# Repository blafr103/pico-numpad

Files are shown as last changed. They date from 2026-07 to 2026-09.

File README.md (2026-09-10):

# pico-numpad

Custom-built 17-key USB HID numpad powered by a Raspberry Pi Pico W,
featuring a hand-wired switch matrix, 16×2 LCD interface,
host-integrated PC monitoring, weather display, and onboard calculator.

The enclosure, electronics, and firmware were designed specifically for
this project using CircuitPython with event-driven matrix scanning via
`keypad.KeyMatrix`.

This README documents the hand-wired prototype. A custom two-layer PCB
successor built around a bare RP2040 is documented in
[`hardware/`](hardware/).

## Features

- USB HID numeric keypad
- Event-driven matrix scanning (`keypad.KeyMatrix`)
- 16x2 LCD with switchable views:
  - Clock + weather (current conditions and local time for one of
    four preset Canadian locations; date + time synced from the host)
  - PC stats, 4 cycling pages: overview (CPU/GPU utilization,
    temperature, package power), memory (RAM utilization, DIMM
    temperatures, VRAM), clocks (P/E-core max, GPU, TjMax
    distance), and voltages
  - Calculator (+ - * / with standard precedence; expression on
    row 0, result on Enter; keys are captured while active and
    send nothing to the PC)
  - Lifetime keypress statistics
- NumLock doubles as a momentary Fn key:
  - Fn+0: Clock view; pressed again while on it, cycles the
    weather location
  - Fn+1: PC stats view; pressed again while on it, cycles the
    stat pages
  - Fn+2: Calculator view; pressed again while on it, clears
  - Fn+3: Statistics view
  - Fn+'+': Increase keypad LED brightness
  - Fn+'-': Decrease keypad LED brightness
- Persistent settings (lifetime key counter and LED brightness) are stored in the
CircuitPython filesystem (`/count.txt` on internal flash).
- Automatic LCD backlight/LED timeout after 300 seconds of inactivity
- Optional Python companion application providing local time,
weather (Environment Canada API), and PC hardware monitoring.

<p align="center">
  <table align="center">
    <tr>
      <td align="center" width="450" valign="top">
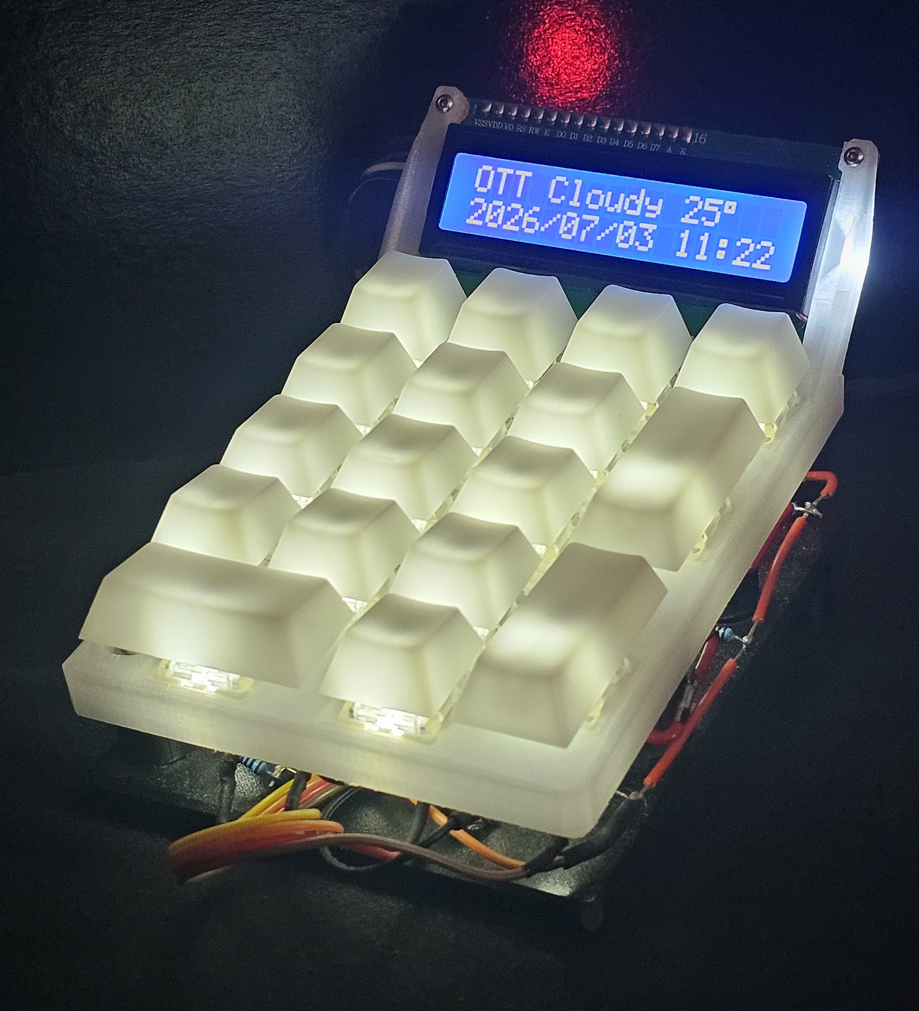
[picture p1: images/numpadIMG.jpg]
        <br>
        <b>Finished Device</b>
      </td>
      <td align="center" width="470" valign="top">
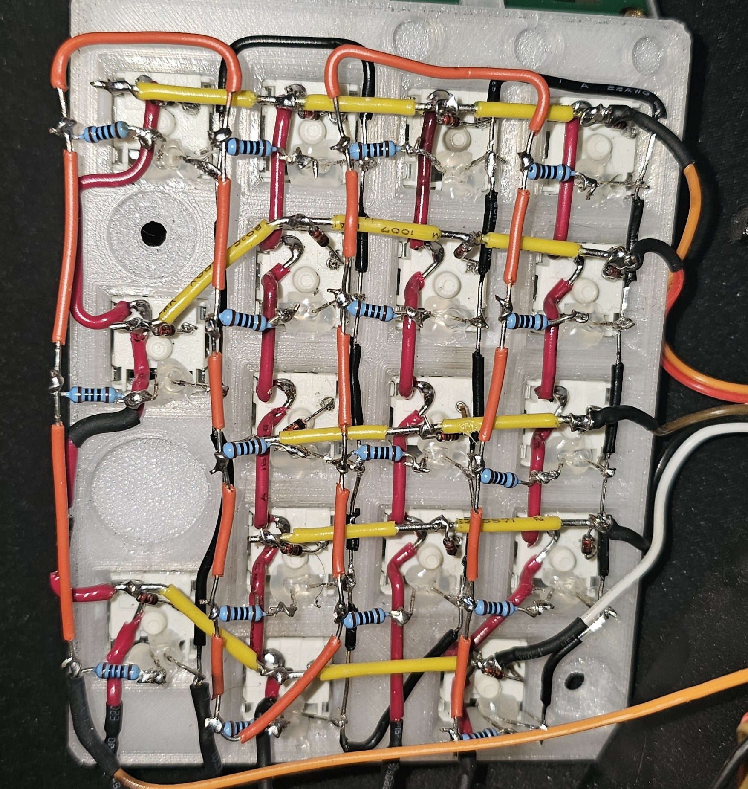
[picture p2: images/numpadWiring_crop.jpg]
        <br>
        <b>Hand-Wired Matrix</b>
      </td>
    </tr>
  </table>
</p>

## Physical Construction

This prototype is entirely hand-built rather than assembled on a PCB. The
hand-wired construction allowed the electrical design, firmware, and enclosure
to be developed and validated before committing to a dedicated PCB. That board
now exists as rev A and is documented in [`hardware/`](hardware/).

### Enclosure

- Designed from scratch in Autodesk Fusion 360
- 3D printed on a Bambu Lab X1 Carbon using PETG for the structural components and translucent polycarbonate (PC) for the light-diffusing enclosure 
- Two-piece printed enclosure with integrated LCD mount and switch plate
- Translucent white PC diffuses the per-key LEDs

### Switches & Keycaps

- Switches: Gateron KS-9 G Pro Black linear switches
- Keycaps: Ranked POM Jelly Premium Translucent keycaps

### Key Matrix

The keypad is wired as a 5×4 switch matrix with one diode per key to eliminate
ghosting.

Color coding throughout the wiring:

| Color | Function |
| :--- | :--- |
| **Red** | Matrix columns |
| **Yellow** | Matrix rows |
| **Orange** | LED power distribution |
| **Black** | LED ground |

Each switch includes a **1N4148** diode (anode toward the row, cathode toward
the column), matching the firmware configuration
(`columns_to_anodes=False`). The matrix layout and diode orientation were
verified using the included `tools/matrix_map_test.py` and
`tools/diode_test.py` utilities.

Note that the rev A PCB in [`hardware/`](hardware/) uses the opposite
orientation (cathode to row).

### Lighting

- One discrete white LED beneath each key
- LEDs share a common PWM-controlled supply, with each LED using its own **100 Ω** current-limiting resistor
- Brightness is adjustable in 12.5% increments using **Fn + '+'** and **Fn + '-'**
- The selected brightness is persisted across power cycles
- LEDs turn off together with the LCD backlight after the inactivity timeout and are restored automatically on activity

### Electronics

- Raspberry Pi Pico W mounted internally
- HD44780-compatible 16×2 LCD with PCF8574 I²C backpack

## Hardware

- Raspberry Pi Pico W (RP2040), CircuitPython 9.2.1
- 16×2 HD44780-compatible LCD with PCF8574 I²C backpack (0x27)
- 17 Gateron KS-9 G Pro Black switches
- Ranked POM Jelly translucent keycaps
- 17 white discrete LEDs
- Rows: GP2–GP6
- Columns: GP12–GP15
- Key LEDs (PWM): GP11
- I²C: SDA GP0 · SCL GP1

## Install

1. Flash CircuitPython 9.x to the Pico.
2. Copy `code.py`, `boot.py`, and `lib/` to the CIRCUITPY drive,
   then power cycle (`boot.py` changes only apply at power-up).
   - On first boot, the firmware creates `/count.txt` to store persistent settings (currently the lifetime keypress count and LED brightness).
3. Install `adafruit_hid` from the
   [CircuitPython 9.x library bundle](https://circuitpython.org/libraries)
   into `lib/`.
4. Optional, for the clock, weather, and PC stats:
   `pip install pyserial requests env_canada` on the PC and run
   `python host/companion.py`. The pad is fully functional without
   it; the clock shows UNKNOWN, weather shows "no weather", and PC
   stats show "no data" until first contact.
   - The Pico exposes two serial ports; the script auto-detects
     the data port, or set PORT in the script manually.
   - PC stats additionally require
     [LibreHardwareMonitor](https://github.com/LibreHardwareMonitor/LibreHardwareMonitor)
     running as administrator with its web server enabled
     (Options - Remote Web Server - Run). Time and weather work
     without it.
   - Weather locations are configured in companion.py as
     label + coordinates + IANA timezone.
   - For hands-off startup on Windows (Task Scheduler setup, logging,
    troubleshooting), see [host/README.md](host/README.md).

## Design

Matrix scanning and debouncing run in C in the background
(`keypad.KeyMatrix`, 10 ms interval); the main loop only consumes
queued edge events, so a busy loop delays input rather than dropping
it. HID output uses `press()`/`release()` on edges so the host sees
real held keys and handles auto-repeat. A hand-written equivalent of
the scanner (polling, per-key debounce state machine) is kept in
[`reference/`](reference/) with a comparison of the two approaches.

`columns_to_anodes=False` is required for this board's diode
orientation; the default silently reads all keys as dead.

`boot.py` remounts the filesystem to allow the firmware to save the
persistent key counter. Holding **NumLock** while connecting the Pico
starts a development mode that leaves the drive writable from the host
and disables persistence.

The LCD is driven with no `sleep()` in the main loop: dirty-flag
rendering (I²C writes only on state change), fixed-width line
overwrites instead of `clear()`, and edge-triggered backlight
control. A full LCD line write costs ~50 ms over I²C, so
unconditional redraws would starve input latency.

The LCD is organized as switchable views (splash on boot, clock,
PC stats, calculator, statistics). Holding **NumLock** acts as a
momentary Fn key: tapping a digit while held switches views without
typing it. A plain NumLock tap is deferred until release so tap and
hold can be distinguished without affecting normal typing. Each view
owns its input: most pass keys through to the PC as normal typing,
while the calculator captures digits and operators entirely
(including suppressing their release events), so nothing leaks to
the host while it is active.

The calculator stores the expression as typed (row 0, scrolling
left past 16 characters) and evaluates on Enter with standard
precedence: tokens are reduced in two passes, folding `*` and `/`
left-to-right first, then summing the remaining `+`/`-` terms.
Divide-by-zero shows Error, cleared by the next digit. After a
result, a digit starts a fresh expression and an operator continues
from the result. Results too wide for the row use scientific
notation. Leaving the view clears it.

Time, weather, and PC stats come from an optional host script
(`host/companion.py`, setup and operation in
[host/README.md](host/README.md)) over a second USB CDC serial port
enabled in `boot.py`. The protocol is newline-terminated ASCII `key:value` lines;
the Pico is a pure listener and the host broadcasts unsolicited (time
on connect and every 30 s, stats every 2 s, weather every 10 min).
The clock free-runs on the crystal between syncs and re-anchors on
every message, bounding drift to one broadcast interval. The RP2040
has no battery-backed RTC, so time is lost at power-off and shows
UNKNOWN until the first sync.

Weather comes from Environment Canada via the `env_canada` package
(nearest site to each configured coordinate). The clock view shows
one location's conditions on row 0 and its local date/time on row 1;
the host sends each location's UTC-offset delta computed fresh with
`zoneinfo`, so DST is handled entirely host-side. Weather older than
30 minutes displays as stale (`LABEL --`); PC stats older than 15
seconds display as "no data".

PC stat rows are composed entirely on the host: companion.py reads
LibreHardwareMonitor's JSON endpoint, selects sensors by hardware
prefix and display name (numeric sensor indices shift between LHM
versions), and sends each page row as a finished 16-character line.
The Pico renders these verbatim, apart from substituting `*` with
the LCD's degree symbol, so adding or reworking a stat page is a
host-only change. Missing sensors render as `--`; the sensor names
target this machine's hardware and need adjusting for others.

Persistent settings (currently the lifetime keypress count and LED brightness) 
are stored in `/count.txt`. To minimize flash wear, writes are batched 
(100 keypresses by default) and also occur immediately after brightness 
changes and when the device transitions to the idle state.

The firmware is organized into independent subsystems for input handling,
LCD rendering, view management, HID output, persistent settings, and host 
communication.

## Future Improvements

- User-configurable key mapping and macros
- More robust persistent configuration storage
  
The custom PCB, integrated USB-C, and per-key RGB lighting items previously
listed here are addressed by the rev A board in [`hardware/`](hardware/).

## Tools

- `tools/matrix_map_test.py` prints (row, col) per keypress; used
  to build/verify the keymap
- `tools/diode_test.py` is a bidirectional scan; verifies diode
  presence and orientation per key

Run either by copying to CIRCUITPY as `code.py` (back up first) and
watching the serial console. Run in dev mode (NumLock at plug-in)
so the drive is writable.

## Credits

LCD driver (`lib/lcd.py`, `lib/i2c_pcf8574_interface.py`):
[dwhall/circuitpython_lcd](https://github.com/dwhall/circuitpython_lcd),
original license headers retained.

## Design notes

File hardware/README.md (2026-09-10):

# pico-numpad - Hardware

Custom two-layer PCB for a 17-key USB numpad with per-key RGB, a rotary encoder, and a 16x2 character LCD. This is the custom-board successor to the hand-wired CircuitPython numpad documented in the repository root, rebuilt around a bare RP2040 with hot-swap switches.
 
**Status - Rev A.** Design complete, DRC clean, full design review passed. Boards fabricated by PCBWay (ENIG) and hand-assembled. Electrical bring-up is **in progress and incomplete** - the board does not yet enumerate over USB and the 3.3 V rail is under investigation. The C firmware targeting this board has been started but is not yet functional. Treat the design as unvalidated.
 
Designed in KiCad 10.

---

## Features

- Bare **RP2040** (not a Pico module) with 16 MB **W25Q128** QSPI flash and a 12 MHz crystal
- **17 hot-swap keys** on Kailh MX sockets (CPG151101S11), any MX-style switch
- **Per-key RGB** - 17x SK6812MINI-E, 5 V data driven through a 74AHCT1G125 level buffer
- **Rotary encoder** with push (EC11), push mapped into the key matrix
- **16x2 HD44780 LCD** over I2C (PCF8574 backpack), driven through an onboard level shifter and connected via header
- **USB-C** with dual 5.1 kΩ CC pulldowns, USBLC6-2SC6 ESD protection, and 27 Ω series termination
- 5x4 diode-per-key matrix, one 1N4148 per switch, **cathode to row** (COL2ROW). This is the reverse of the hand-wired build, which is wired anode to row.
- BOOTSEL and RESET buttons, SWD header
- Screws enter from either face (bottom edge extended so the lower mounting holes clear the 0 and Enter keycaps)

---

## Repository layout

```
hardware/
├── README.md                            this file
├── numpad/
│   ├── numpad.kicad_pro                 KiCad project
│   ├── numpad.kicad_prl                 project-local settings (editor state, netclasses)
│   ├── numpad.kicad_pcb                 board
│   ├── numpad.kicad_sch                 schematic, root sheet
│   ├── 01_power_usb.kicad_sch           USB-C, ESD, 3.3 V regulator
│   ├── 02_mcu.kicad_sch                 RP2040, QSPI flash, crystal, SWD, BOOTSEL/RESET
│   ├── 03_matrix.kicad_sch              key matrix and rotary encoder
│   ├── 04_rgb.kicad_sch                 SK6812 chain and 74AHCT1G125 buffer
│   ├── 05_ui.kicad_sch                  LCD header and I2C level shifters
│   ├── fp-lib-table                     footprint library table
│   ├── sym-lib-table                    symbol library table
│   ├── numpad.csv                       BOM export from the schematic
│   ├── part-numbers.txt                 working notes on ordered part numbers
│   ├── lib/marbastlib/                  git submodule - MX symbols/footprints, Kailh sockets
│   ├── plot-files/                      raw KiCad plot output - all gerbers, both drill maps, DXF, drills
│   ├── numpad-revA-fab/                 cleaned fab set actually sent to the fab (12 files)
│   ├── numpad-revA-fab.zip              the same set, zipped for upload
│   ├── step-files/                      board STEP for the enclosure model
│   └── W1129510AS1K1.pdf                PCBWay order document, W1129510AS1K1
├── stencil_gerbers/                     paste and outline set sent for the SMD stencils
├── stencil_gerbers.zip                  the same set, zipped for upload
├── production file W1129510AS1K2/       PCBWay's returned CAM data for W1129510AS1K2
└── production file W1129510AS1K2.zip    the same, as delivered
```

`numpad/lib/marbastlib` is a submodule. After cloning:

```
git submodule update --init --recursive
```

---

## Board summary

| | |
|---|---|
| Size | 83 x 127 mm |
| Layers | 2 |
| Thickness | 1.6 mm |
| Copper | 1 oz |
| Min track / clearance | 0.2 mm / 0.15 mm |
| Vias | 0.6 / 0.3 mm |
| Footprints | 120 |

Switches and RGB are surface-mount on the **back** copper (marbastlib MX footprints are authored for back-side placement). The USB/MCU/encoder strip sits along the top edge on the front.

---

## Key matrix

17 keys plus the encoder push occupy 18 of the 20 cells in a 5x4 grid. The 2u-tall `+` and `Enter` keys each take a single electrical cell, at R1C3 and R4C3, which leaves R2C3 free for the encoder push and R3C3 unused. The 2u-wide `0` key leaves R4C1 unused.

| | C0 | C1 | C2 | C3 |
|----|-----|---|-----|---|
| R0 | Num | / | * | - |
| R1 | 7 | 8 | 9 | + |
| R2 | 4 | 5 | 6 | Encoder push |
| R3 | 1 | 2 | 3 | (unused) |
| R4 | 0 | (unused) | .  | Enter |

---

## Notable ICs and interfaces

| Ref | Part | Role |
|-----|---|---|
| U3  | RP2040 | MCU, QFN-56, 0.4 mm pitch |
| U4  | W25Q128JVS | 16 MB QSPI program flash |
| U1  | NCP1117-3.3 | 3.3 V LDO (see substitution note below) |
| U2  | USBLC6-2SC6 | USB ESD protection |
| U5  | 74AHCT1G125 | 3.3 V to 5 V buffer for the RGB data line |
| Q1/Q2 | BSS138 x2 | I2C level shift for the LCD header |
| J1  | USB-C receptacle (HRO TYPE-C-31-M-12) | Power and data |
| J2  | SWD header | Debug |
| J3  | LCD header | I2C to the character LCD |

Exact GPIO assignments live in the schematic and are the source of truth for firmware. Verified against the KiCad netlist: RGB data on **GP11**, encoder A/B on **GP7/GP8**. The matrix rows (GP2-GP6), columns (GP12-GP15), and I2C (GP0/GP1) carry over unchanged from the hand-wired build. GP11 changes role, it drove the single-colour LED PWM on the hand-wired unit and drives the SK6812 chain here. The encoder is new to this board.

---

## Ordering this board

Fab specs, all inside a standard 2-layer capability:
 
- 2-layer, 1.6 mm FR-4, 1 oz copper
- 6/6 mil track/space class, 0.3 mm minimum drill
- **ENIG recommended.** The RP2040 is a 0.4 mm-pitch QFN-56 - a flat immersion-gold finish wets far more predictably under hand soldering than domed HASL
- 
The board has **6 intentional plated slots** (4 at the USB-C connector shield legs, 2 at the encoder bracket), written as route-mode Excellon (`G00/M15/M16`) rather than G85. Most CAM tools read this correctly, but it is worth confirming in the fab's gerber viewer that they render as elongated openings.

---

## Assembly and bring-up

The board is designed for **staged bring-up**, not a single reflow:
 
1. Populate the USB-C and regulator section first. Scope the 3.3 V rail under a ~100 Ω load (AC-coupled, bandwidth-limited, short ground spring) and confirm it is not oscillating **before** placing the RP2040.
2. Then place the MCU, flash, and crystal, and confirm enumeration over USB.
3. Then the switch matrix, encoder, RGB chain, and LCD header.

Two part choices worth considering before assembly:
 
- **Regulator.** The board is drawn for the NCP1117ST33T3G, but C2 is a 10 µF MLCC that sits below that regulator's 0.25-2.2 Ω output-ESR floor. If the 3.3 V rail oscillates, swap in a ceramic-stable **TLV1117-33** (same SOT-223 pinout, drop-in). Recommend ordering both for cheap insurance.
- **Crystal.** 12 MHz 3225, chosen for **CL ≈ 18 pF** to match the 27 pF loading caps. Check the specific part's max ESR - higher-CL parts trend higher ESR, and higher CL also slows startup, which may need the pico-sdk XOSC startup multiplier raised. A CL = 10 pF part with 15 pF caps is a BOM-only fallback if either becomes a problem.

---

## Firmware

The hand-wired numpad in the repository root runs **CircuitPython** on a Pico W. That firmware does **not** port directly to this board - the bare RP2040 boot flow, the encoder, and RGB (vs single-color PWM) all differ, as does the diode orientation. The matrix and I2C pin assignments do carry over.
 
The custom board is designed to run a **C firmware on pico-sdk + TinyUSB**. That rewrite has been started and is not yet functional.

---

## License

The files in this repository are covered by the license terms in the repository root.
 
The KiCad symbols and footprints under `numpad/lib/marbastlib` are a git submodule of [ebastler/marbastlib](https://github.com/ebastler/marbastlib), licensed **CERN-OHL-P-2.0**. Those terms, including its notice requirements, apply to that library and to the footprints used from it.

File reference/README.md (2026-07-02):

# reference

manual_scan.py is a hand-written implementation of what
keypad.KeyMatrix does internally. Functional, but not the production
firmware (see code.py at repo root).

## Manual polling vs KeyMatrix

manual_scan.py scans in Python inside the main loop, so the matrix
is only observed while scan() runs and the debounce sampling period
jitters with loop timing. State is a shared array with no history:
a press and release between two scans is lost, and a stalled loop
can desync HID state.

code.py uses KeyMatrix: scanning runs in C on a fixed 10 ms timer,
independent of the main loop, and debounced edges are delivered
through an event queue. A stalled loop delays input instead of
dropping it.

Bare-metal analogue: busy-wait polling vs timer-ISR capture feeding
a ring buffer — same pattern as UART FIFOs.

## Debounce

manual_scan.py implements a per-key stability window: a raw state
change is committed only after 10 ms without further change, so
contact bounce keeps resetting the timer and never commits. This is
the standard algorithm, as opposed to lockout-style debounce (fire
immediately, then ignore for N ms), which acts on possibly-bouncing
first readings and blocks legitimate fast re-presses.

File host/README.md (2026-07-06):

# Host companion

`companion.py` broadcasts time, weather, and PC hardware stats to the
numpad over its second USB CDC serial port. The pad works without it -
this script only feeds the clock, weather, and PC stats views. Protocol
and message format: see the [Design section](../README.md#design) of
the main README and the header comment in `companion.py`.

## Requirements

- Python 3.9+ with `pyserial`, `requests`, `env_canada`
  (`pip install pyserial requests env_canada`)
- [LibreHardwareMonitor](https://github.com/LibreHardwareMonitor/LibreHardwareMonitor)
  running as administrator with its web server enabled
  (Options - Remote Web Server - Run) - needed for PC stats only.
  Time and weather work without it.

## Running manually

    python companion.py

There is no console output. Everything, including the "connected"
message and errors, goes to `companion.log` beside the script (see
Logging). The Pico exposes two serial ports; the script auto-detects
the data port, or set `PORT` at the top of the script.

Only one instance can hold the serial port. If a scheduled instance
is already running (see below), stop it first, otherwise the manual
run loops on "disconnected, retrying" without ever connecting.

## Automatic startup (Windows)

Two pieces need to start at logon: LibreHardwareMonitor and
companion.py.

### LibreHardwareMonitor

Use its own options: Run On Windows Startup, Start Minimized,
Minimize To Tray, and Remote Web Server. LHM registers its own
elevated startup task, so UAC is handled for you.

### companion.py via Task Scheduler

The script runs under `pythonw.exe`, the windowless twin of
`python.exe` that ships in the same folder - no console window,
which is also why logging goes to a file (under pythonw, `print()`
output is silently discarded).

**Finding the interpreter.** Do not use paths under
`...\AppData\Local\Microsoft\WindowsApps\` - those are Microsoft
Store stubs, not real executables, and Task Scheduler launching the
pythonw stub exits silently with result 0x1. Get the real path with:

    python -c "import sys; print(sys.executable)"

and use the `pythonw.exe` in that same folder.

**Task configuration** (Task Scheduler - Create Task, not the Basic
wizard):

- General: Run only when user is logged on (keeps the task in your
  session, where LHM's web server and your COM port permissions live).
  Highest privileges not needed.
- Trigger: At log on, and in the same dialog check
  "Repeat task every: 5 minutes" for a duration of "Indefinitely"
  (the dialog defaults to 30 minutes - change it).
- Action: Start a program.
  - Program/script: full path to `pythonw.exe`
  - Arguments: full path to `companion.py`, quoted
  - Start in: the script's folder, not quoted (this field rejects
    quotes)
  The interpreter is the program and the script is its argument
  because Task Scheduler executes the program field directly as a
  process - it does not go through file-association logic, so
  pointing it at the .py file is unreliable.
- Settings:
  - Uncheck "Stop the task if it runs longer than 3 days"
  - "If the task fails, restart every 1 minute", 3 attempts
  - "If the task is already running: Do not start a new instance"

**How the watchdog works.** The 5-minute repeat tick tries to start
the task; "Do not start a new instance" makes that a no-op while the
script is alive. If the process ever dies - crash, clean exit, or
killed - the next tick resurrects it. The failure-restart setting
covers non-zero exits faster (1 minute), and the repeat covers
everything else.

**Testing note.** Repetition belongs to the trigger, and only arms
when the trigger actually fires. A manual right-click Run creates an
instance with no trigger behind it - kill that and nothing restarts
it. To test the watchdog for real: log off and back on, verify
pythonw.exe is running (Task Manager, Details tab), kill it, and
wait up to ~6 minutes.

## Logging

`companion.log` beside the script, rotating at 500 KB with 2 backups
(~1.5 MB cap). Logged events: connect/disconnect of the Pico's port,
per-location weather failures, and full tracebacks for any crash
(the script exits non-zero on a crash so the task's failure-restart
fires).

## Troubleshooting

First stop for any problem is `companion.log`. Then:

| Symptom | Likely cause | Check |
| --- | --- | --- |
| Stat pages say "LHM down" | LHM not running, not admin, or web server off | LHM tray icon; `http://localhost:8085/data.json` in a browser |
| Stat pages say "no data" | companion.py not running or Pico port not found | Task Manager Details for pythonw.exe; log for "no Pico data port" |
| Clock says UNKNOWN | No time message received since power-up | Same as above - the clock has no RTC and needs one sync |
| Weather shows "no weather" or `LABEL --` | env_canada fetch failing or data stale (>30 min) | Log for "wx ... failed" lines |
| Task shows Last Run Result 0x1, no process | WindowsApps stub as the program, or missing packages | Program path in the task's Action; run the same folder's python.exe in a console to see the error |
| Manual run connects nothing, log says "disconnected, retrying" forever | Scheduled instance already holds the COM port | End the running task before manual runs |
| Stats stuck / values look wrong for your PC | Sensor names target the original machine (i7-13700K, RTX 4080) | Adjust the `find()` names in `stat_pages()` against your LHM tree |

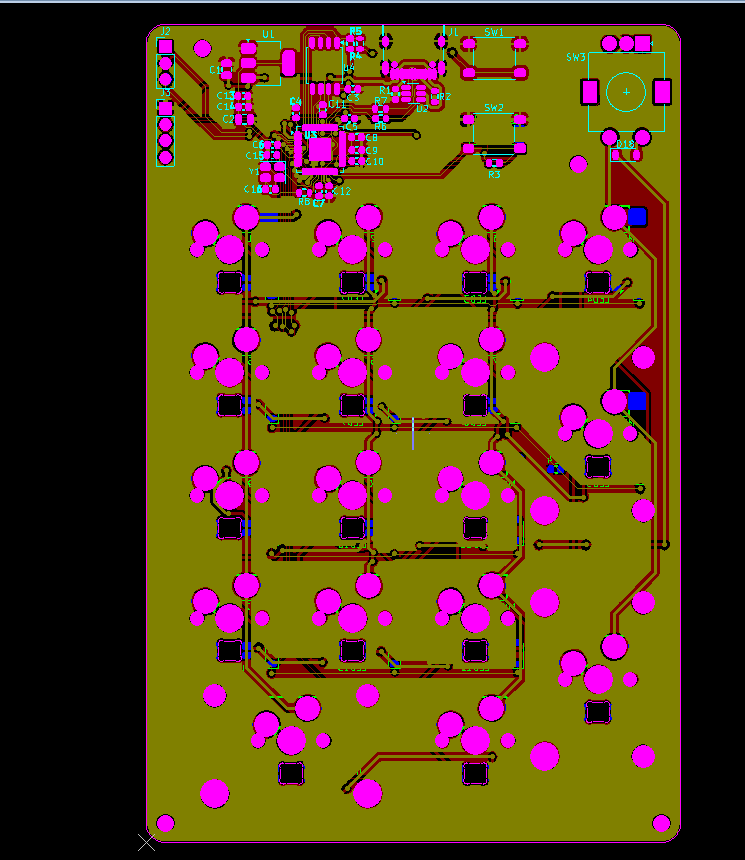
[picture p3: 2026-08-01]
hardware/production file W1129510AS1K2/W1129510AS1K2.png

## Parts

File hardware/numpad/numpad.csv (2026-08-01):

Reference | Qty | Value | DNP | Exclude from BOM | Exclude from Board | Footprint | Datasheet
C1,C2 | 2 | 10u |  |  |  | Capacitor_SMD:C_0805_2012Metric
C3,C5,C11 | 3 | 1u |  |  |  | Capacitor_SMD:C_0603_1608Metric
C4,C6,C7,C8,C9,C10,C12,C13,C14,C17,C18,C19,C20,C21,C22,C23,C24,C25,C26,C27,C28,C29,C30,C31,C32,C33,C34 | 27 | 100n |  |  |  | Capacitor_SMD:C_0603_1608Metric
C15,C16 | 2 | 27p |  |  |  | Capacitor_SMD:C_0603_1608Metric
C35,C36 | 2 | 22u |  |  |  | Capacitor_SMD:C_0805_2012Metric
D1,D2,D3,D4,D5,D6,D7,D8,D9,D10,D11,D12,D13,D14,D15,D16,D17,D18 | 18 | 1N4148W |  |  |  | Diode_SMD:D_SOD-123 | https://www.vishay.com/docs/85748/1n4148w.pdf
J1 | 1 | USB_C_Receptacle_USB2.0_16P |  |  |  | Connector_USB:USB_C_Receptacle_HRO_TYPE-C-31-M-12 | https://www.usb.org/sites/default/files/documents/usb_type-c.zip
J2 | 1 | Conn_01x03 |  |  |  | Connector_PinHeader_2.54mm:PinHeader_1x03_P2.54mm_Vertical
J3 | 1 | Conn_01x04 |  |  |  | Connector_PinHeader_2.54mm:PinHeader_1x04_P2.54mm_Vertical
LED1,LED2,LED3,LED4,LED5,LED6,LED7,LED8,LED9,LED10,LED11,LED12,LED13,LED14,LED15,LED16,LED17 | 17 | MX_SK6812MINI-E |  |  |  | PCM_marbastlib-mx:LED_MX_6028R
MX1 | 1 | NUM |  |  |  | PCM_marbastlib-mx:SW_MX_HS_CPG151101S11_1u
MX2 | 1 | DIV |  |  |  | PCM_marbastlib-mx:SW_MX_HS_CPG151101S11_1u
MX3 | 1 | MULT |  |  |  | PCM_marbastlib-mx:SW_MX_HS_CPG151101S11_1u
MX4 | 1 | MIN |  |  |  | PCM_marbastlib-mx:SW_MX_HS_CPG151101S11_1u
MX5 | 1 | 7 |  |  |  | PCM_marbastlib-mx:SW_MX_HS_CPG151101S11_1u
MX6 | 1 | 8 |  |  |  | PCM_marbastlib-mx:SW_MX_HS_CPG151101S11_1u
MX7 | 1 | 9 |  |  |  | PCM_marbastlib-mx:SW_MX_HS_CPG151101S11_1u
MX8 | 1 | PLUS |  |  |  | PCM_marbastlib-mx:SW_MX_HS_CPG151101S11_1u
MX9 | 1 | 4 |  |  |  | PCM_marbastlib-mx:SW_MX_HS_CPG151101S11_1u
MX10 | 1 | 5 |  |  |  | PCM_marbastlib-mx:SW_MX_HS_CPG151101S11_1u
MX11 | 1 | 6 |  |  |  | PCM_marbastlib-mx:SW_MX_HS_CPG151101S11_1u
MX12 | 1 | 1 |  |  |  | PCM_marbastlib-mx:SW_MX_HS_CPG151101S11_1u
MX13 | 1 | 2 |  |  |  | PCM_marbastlib-mx:SW_MX_HS_CPG151101S11_1u
MX14 | 1 | 3 |  |  |  | PCM_marbastlib-mx:SW_MX_HS_CPG151101S11_1u
MX15 | 1 | 0 |  |  |  | PCM_marbastlib-mx:SW_MX_HS_CPG151101S11_1u
MX16 | 1 | PERIOD |  |  |  | PCM_marbastlib-mx:SW_MX_HS_CPG151101S11_1u
MX17 | 1 | ENTER |  |  |  | PCM_marbastlib-mx:SW_MX_HS_CPG151101S11_1u
Q1,Q2 | 2 | BSS138 |  |  |  | Package_TO_SOT_SMD:SOT-23 | https://www.onsemi.com/pub/Collateral/BSS138-D.PDF
R1,R2 | 2 | 5k1 |  |  |  | Resistor_SMD:R_0603_1608Metric
R3,R4 | 2 | 10k |  |  |  | Resistor_SMD:R_0603_1608Metric
R5,R8 | 2 | 1k |  |  |  | Resistor_SMD:R_0603_1608Metric
R6,R7 | 2 | 27 |  |  |  | Resistor_SMD:R_0603_1608Metric
R9 | 1 | 470 |  |  |  | Resistor_SMD:R_0603_1608Metric
R10,R11 | 2 | 4k7 |  |  |  | Resistor_SMD:R_0603_1608Metric
SW1 | 1 | BOOTSEL |  |  |  | Button_Switch_SMD:SW_SPST_PTS645Sx43SMTR92
SW2 | 1 | RESET |  |  |  | Button_Switch_SMD:SW_SPST_PTS645Sx43SMTR92
SW3 | 1 | RotaryEncoder_Switch |  |  |  | Rotary_Encoder:RotaryEncoder_Alps_EC11E-Switch_Vertical_H20mm
U1 | 1 | NCP1117-3.3_SOT223 |  |  |  | Package_TO_SOT_SMD:SOT-223-3_TabPin2 | http://www.onsemi.com/pub_link/Collateral/NCP1117-D.PDF
U2 | 1 | USBLC6-2SC6 |  |  |  | Package_TO_SOT_SMD:SOT-23-6 | https://www.st.com/resource/en/datasheet/usblc6-2.pdf
U3 | 1 | RP2040 |  |  |  | Package_DFN_QFN:QFN-56-1EP_7x7mm_P0.4mm_EP3.2x3.2mm | https://datasheets.raspberrypi.com/rp2040/rp2040-datasheet.pdf
U4 | 1 | W25Q128JVS |  |  |  | Package_SO:SOIC-8_5.3x5.3mm_P1.27mm | https://www.winbond.com/resource-files/w25q128jv_dtr%20revc%2003272018%20plus.pdf
U5 | 1 | 74AHCT1G125 |  |  |  | Package_TO_SOT_SMD:SOT-23-5 | http://www.ti.com/lit/sg/scyt129e/scyt129e.pdf
Y1 | 1 | 12MHz |  |  |  | Crystal:Crystal_SMD_3225-4Pin_3.2x2.5mm

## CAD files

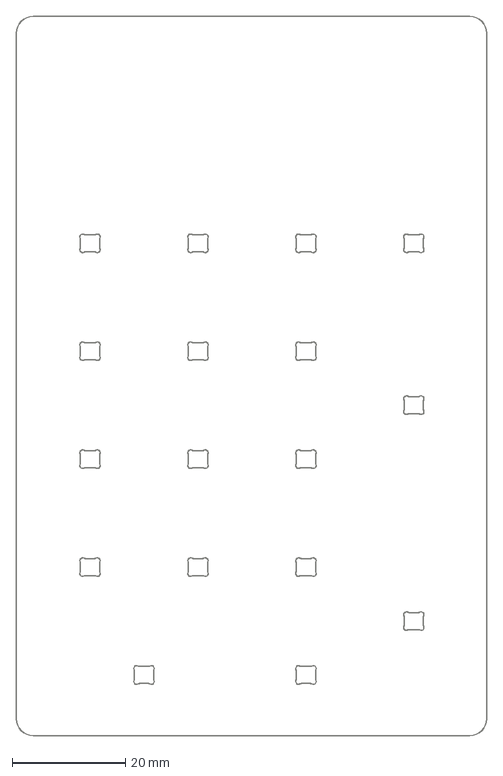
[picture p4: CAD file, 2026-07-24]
hardware/numpad/plot-files/numpad-Edge_Cuts.dxf
83.0 x 127.0 mm

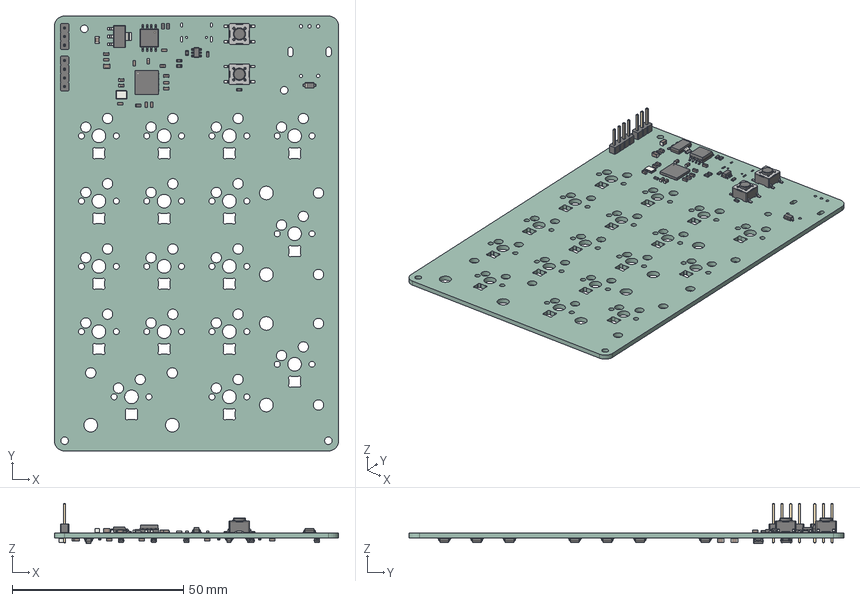
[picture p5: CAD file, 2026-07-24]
hardware/numpad/step-files/numpad-step.step
83.0 x 127.0 x 11.8 mm
QFN-56-1EP_7x7mm_P0.4mm_EP3.2x3.2mm
R_0603_1608Metric x 11
C_0603_1608Metric x 32
PinHeader_1x03_P254mm_Vertical
SOT-223
D_SOD-123 x 18
PinHeader_1x04_P254mm_Vertical
C_0805_2012Metric x 4
SW_SPST_PTS645Sx43SMTR92 x 2
Crystal_SMD_3225-4Pin_3.2x2.5mm
SOIC-8_5.3x5.3mm_P1.27mm
SOT-23-6
SOT-23 x 2
SOT-23-5
numpad_PCB

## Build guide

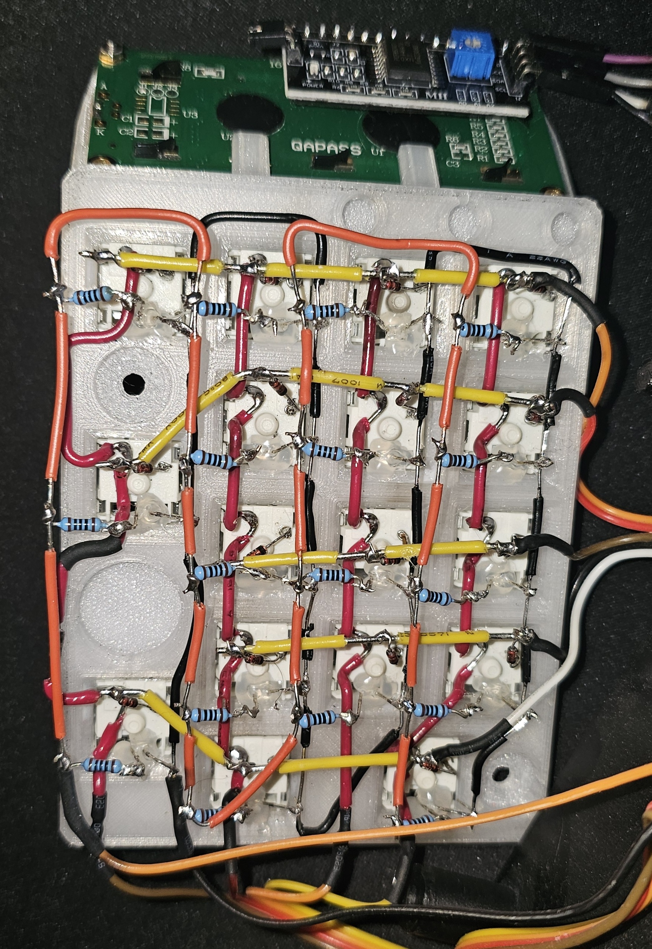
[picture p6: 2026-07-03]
images/numpadWiring.jpg

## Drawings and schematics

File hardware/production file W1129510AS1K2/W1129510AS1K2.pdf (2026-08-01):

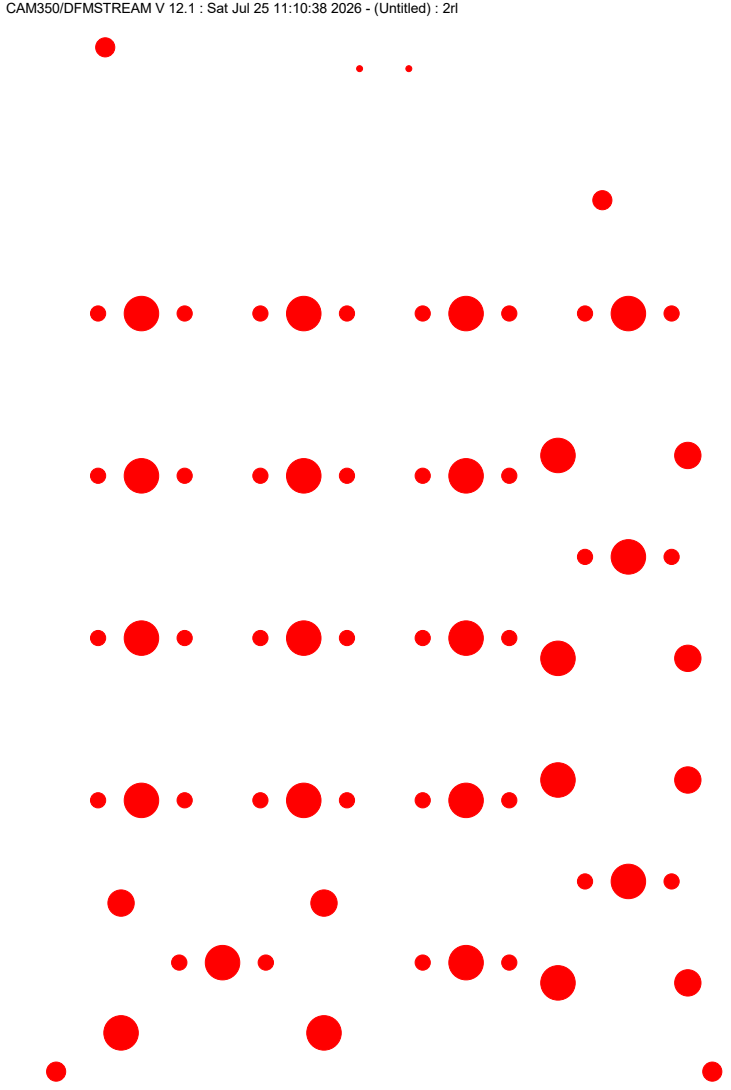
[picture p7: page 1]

CAM350/DFMSTREAM V 12.1 : Sat Jul 25 11:10:38 2026 - (Untitled) : 2rl

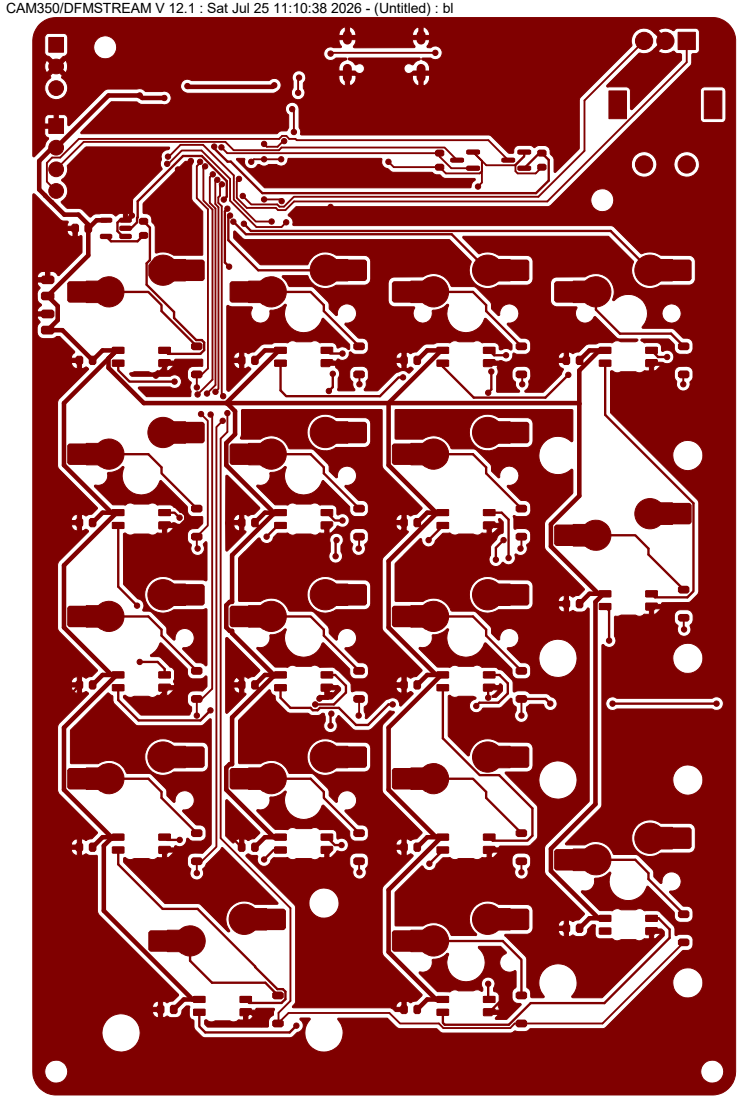
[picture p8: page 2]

CAM350/DFMSTREAM V 12.1 : Sat Jul 25 11:10:38 2026 - (Untitled) : bl

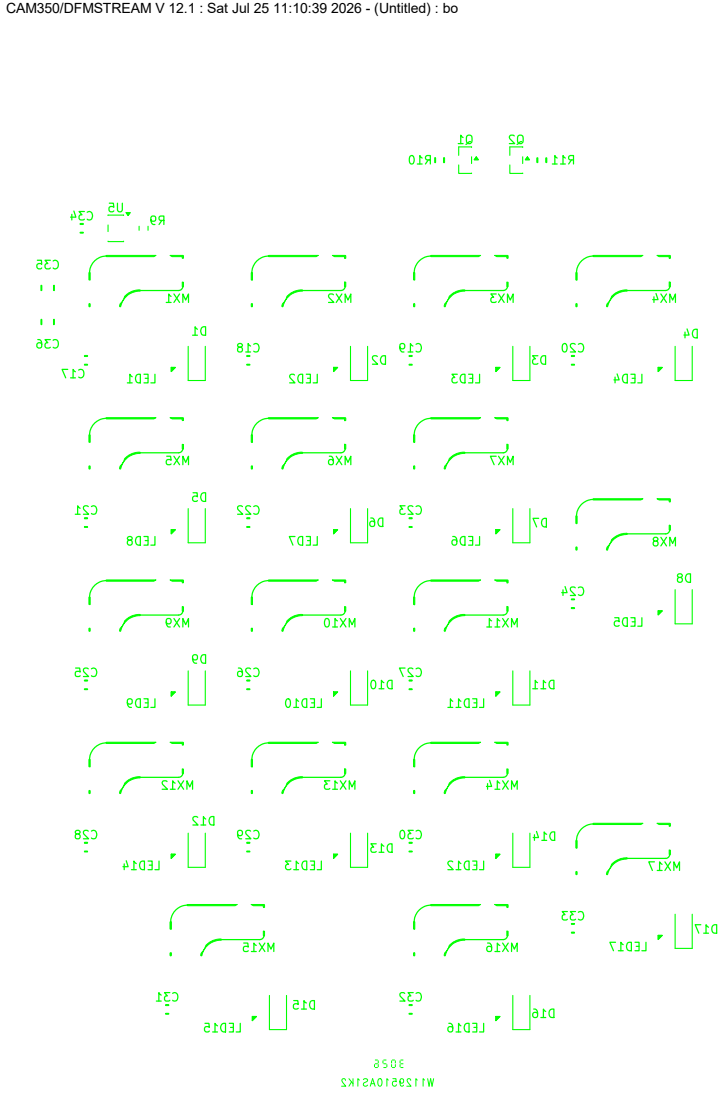
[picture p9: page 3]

CAM350/DFMSTREAM V 12.1 : Sat Jul 25 11:10:39 2026 - (Untitled) : bo

CAM350/DFMSTREAM V 12.1 : Sat Jul 25 11:10:39 2026 - (Untitled) : bp

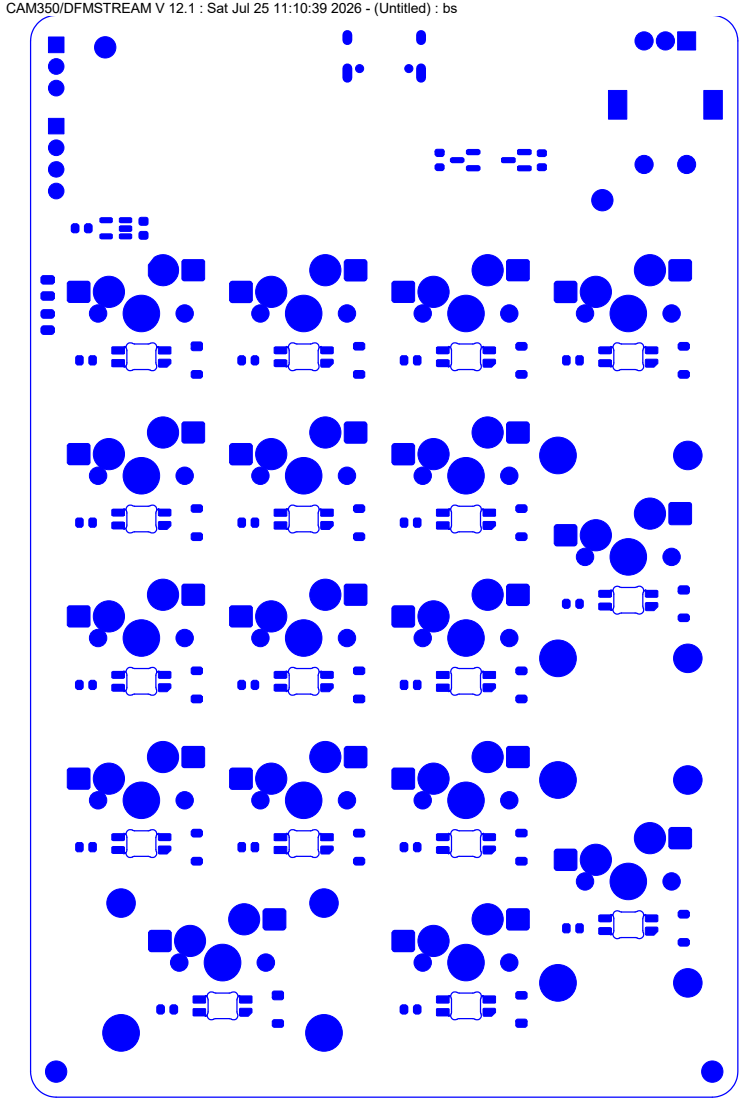
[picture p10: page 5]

CAM350/DFMSTREAM V 12.1 : Sat Jul 25 11:10:39 2026 - (Untitled) : bs

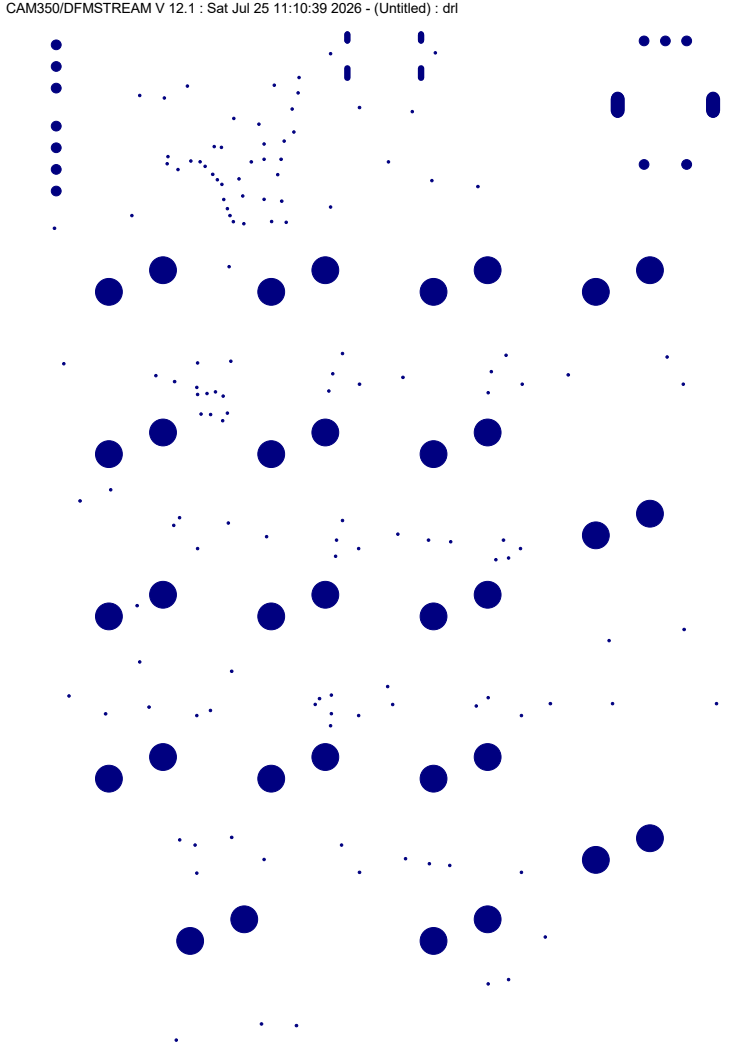
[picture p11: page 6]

CAM350/DFMSTREAM V 12.1 : Sat Jul 25 11:10:39 2026 - (Untitled) : drl

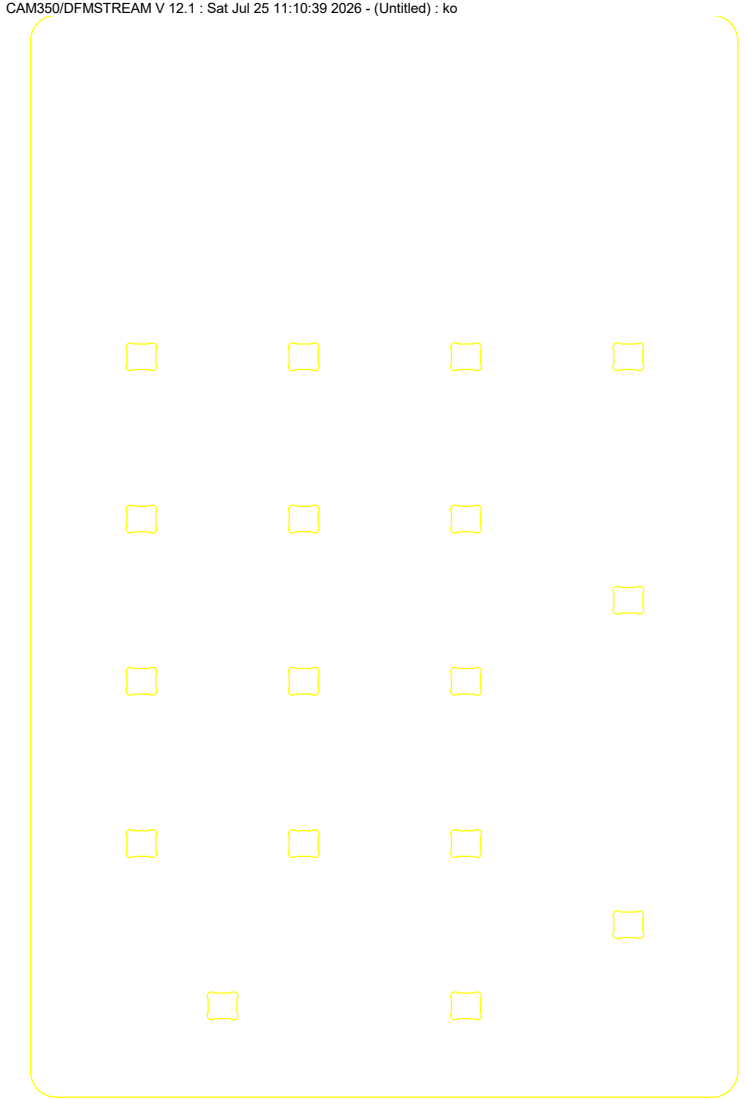
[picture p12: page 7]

CAM350/DFMSTREAM V 12.1 : Sat Jul 25 11:10:39 2026 - (Untitled) : ko

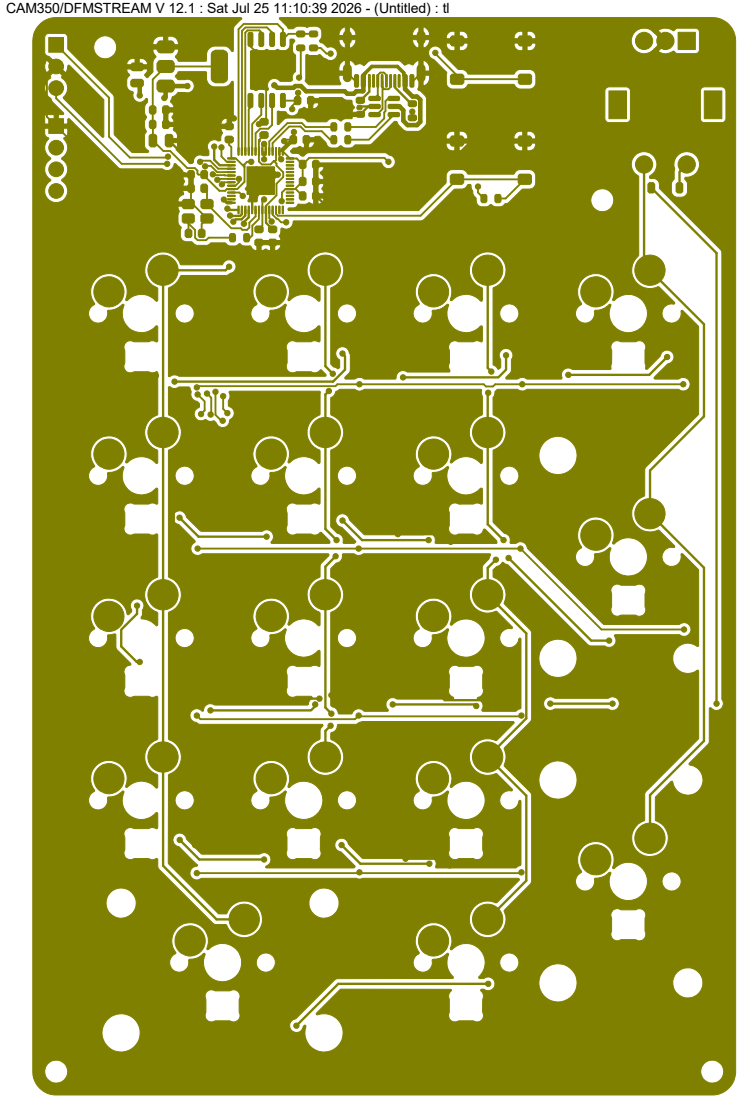
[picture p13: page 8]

CAM350/DFMSTREAM V 12.1 : Sat Jul 25 11:10:39 2026 - (Untitled) : tl

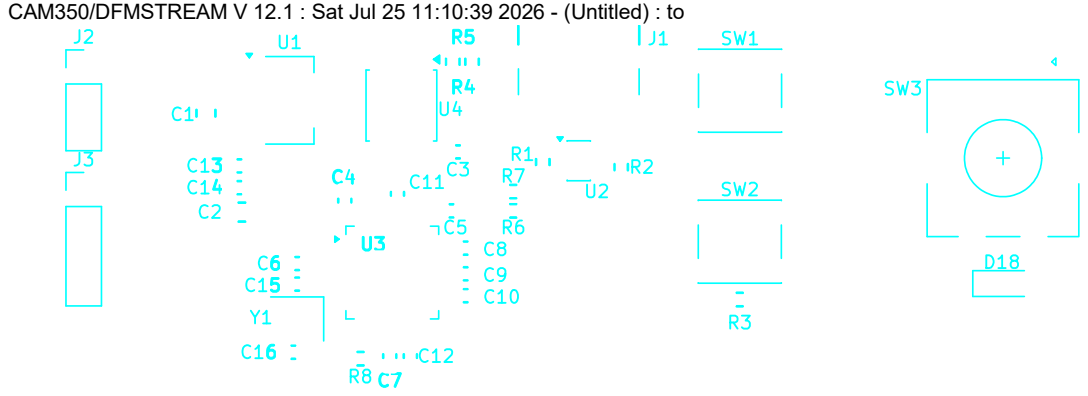
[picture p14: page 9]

CAM350/DFMSTREAM V 12.1 : Sat Jul 25 11:10:39 2026 - (Untitled) : to

CAM350/DFMSTREAM V 12.1 : Sat Jul 25 11:10:39 2026 - (Untitled) : tp

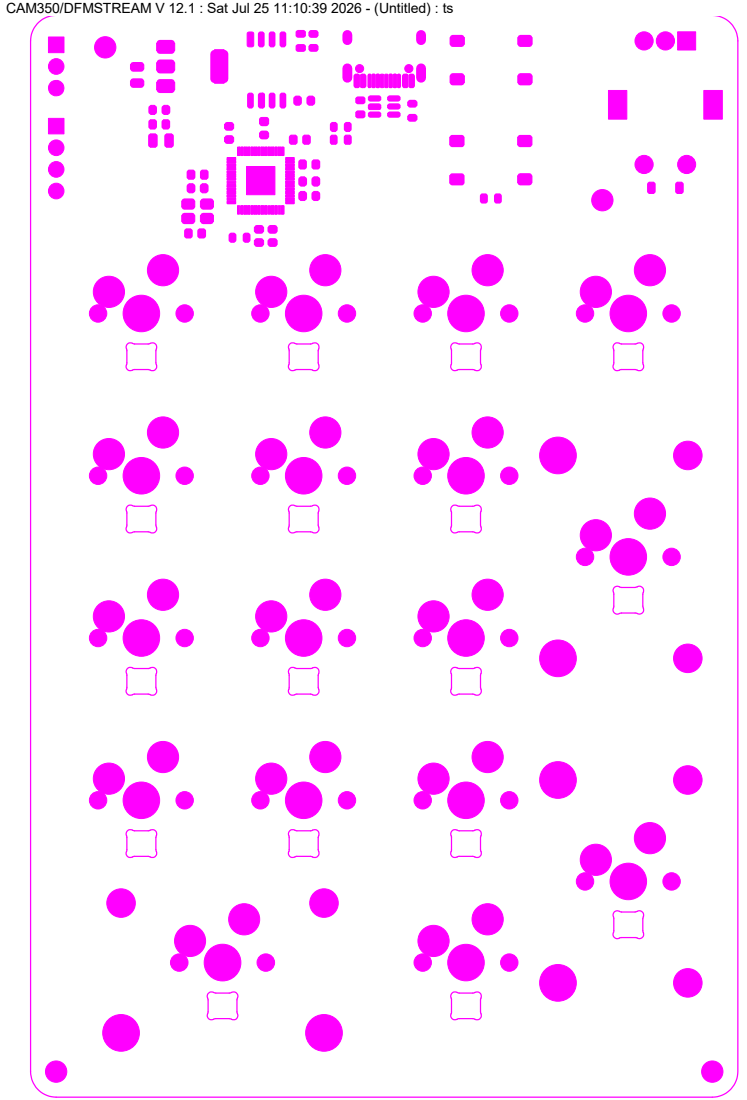
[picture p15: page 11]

CAM350/DFMSTREAM V 12.1 : Sat Jul 25 11:10:39 2026 - (Untitled) : ts

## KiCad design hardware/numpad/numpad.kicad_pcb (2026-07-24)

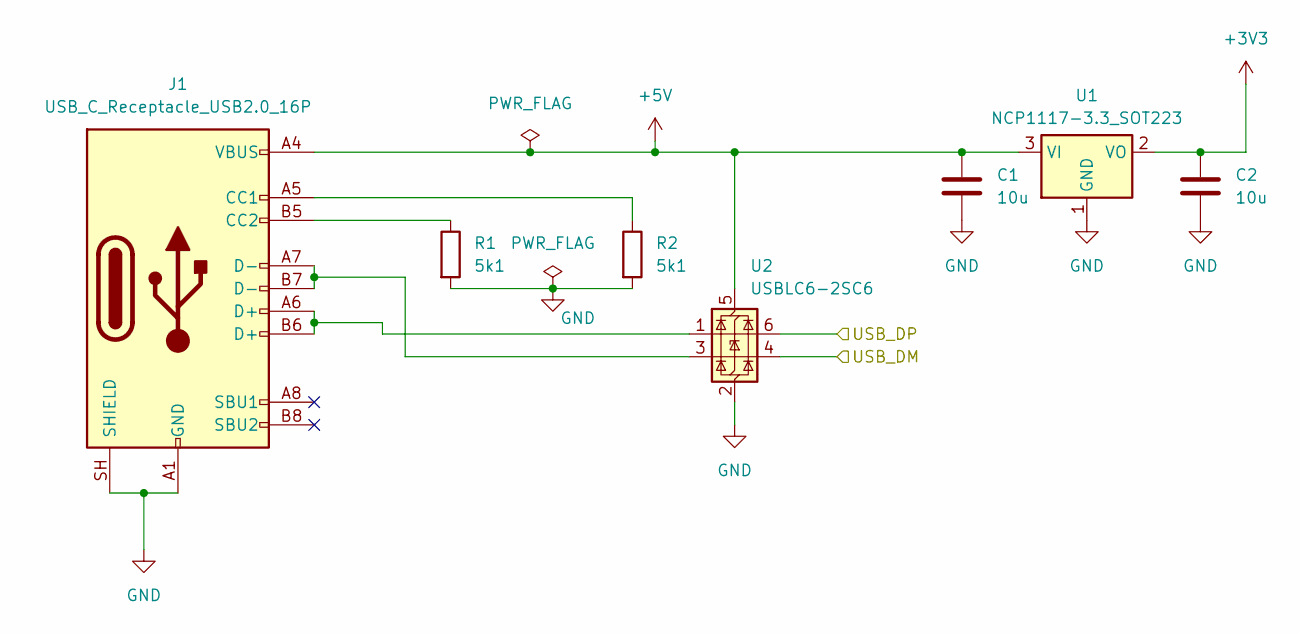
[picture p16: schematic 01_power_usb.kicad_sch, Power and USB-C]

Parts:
C1, C2: 10u; C_0805_2012Metric
J1: USB_C_Receptacle_USB2.0_16P; USB_C_Receptacle_HRO_TYPE-C-31-M-12
R1, R2: 5k1; R_0603_1608Metric
U1: NCP1117-3.3_SOT223; SOT-223-3_TabPin2
U2: USBLC6-2SC6; SOT-23-6

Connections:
+3V3: C2.1, U1.2 (VO); also elsewhere on the board
+5V: C1.1, J1.A4 (VBUS), J1.A9 (VBUS), J1.B4 (VBUS), J1.B9 (VBUS), U1.3 (VI), U2.5 (VBUS); also elsewhere on the board
/01_power_usb/USB_DM: U2.4 (I/O2); also elsewhere on the board
/01_power_usb/USB_DP: U2.6 (I/O1); also elsewhere on the board
GND: C1.2, C2.2, J1.A1 (GND), J1.A12 (GND), J1.B1 (GND), J1.B12 (GND), J1.SH (SHIELD), R1.2, R2.2, U1.1 (GND), U2.2 (GND); also elsewhere on the board
unnamed: J1.A5 (CC1), R2.1
unnamed: J1.B5 (CC2), R1.1
unnamed: J1.A6 (D+), J1.B6 (D+), U2.1 (I/O1)
unnamed: J1.A7 (D-), J1.B7 (D-), U2.3 (I/O2)

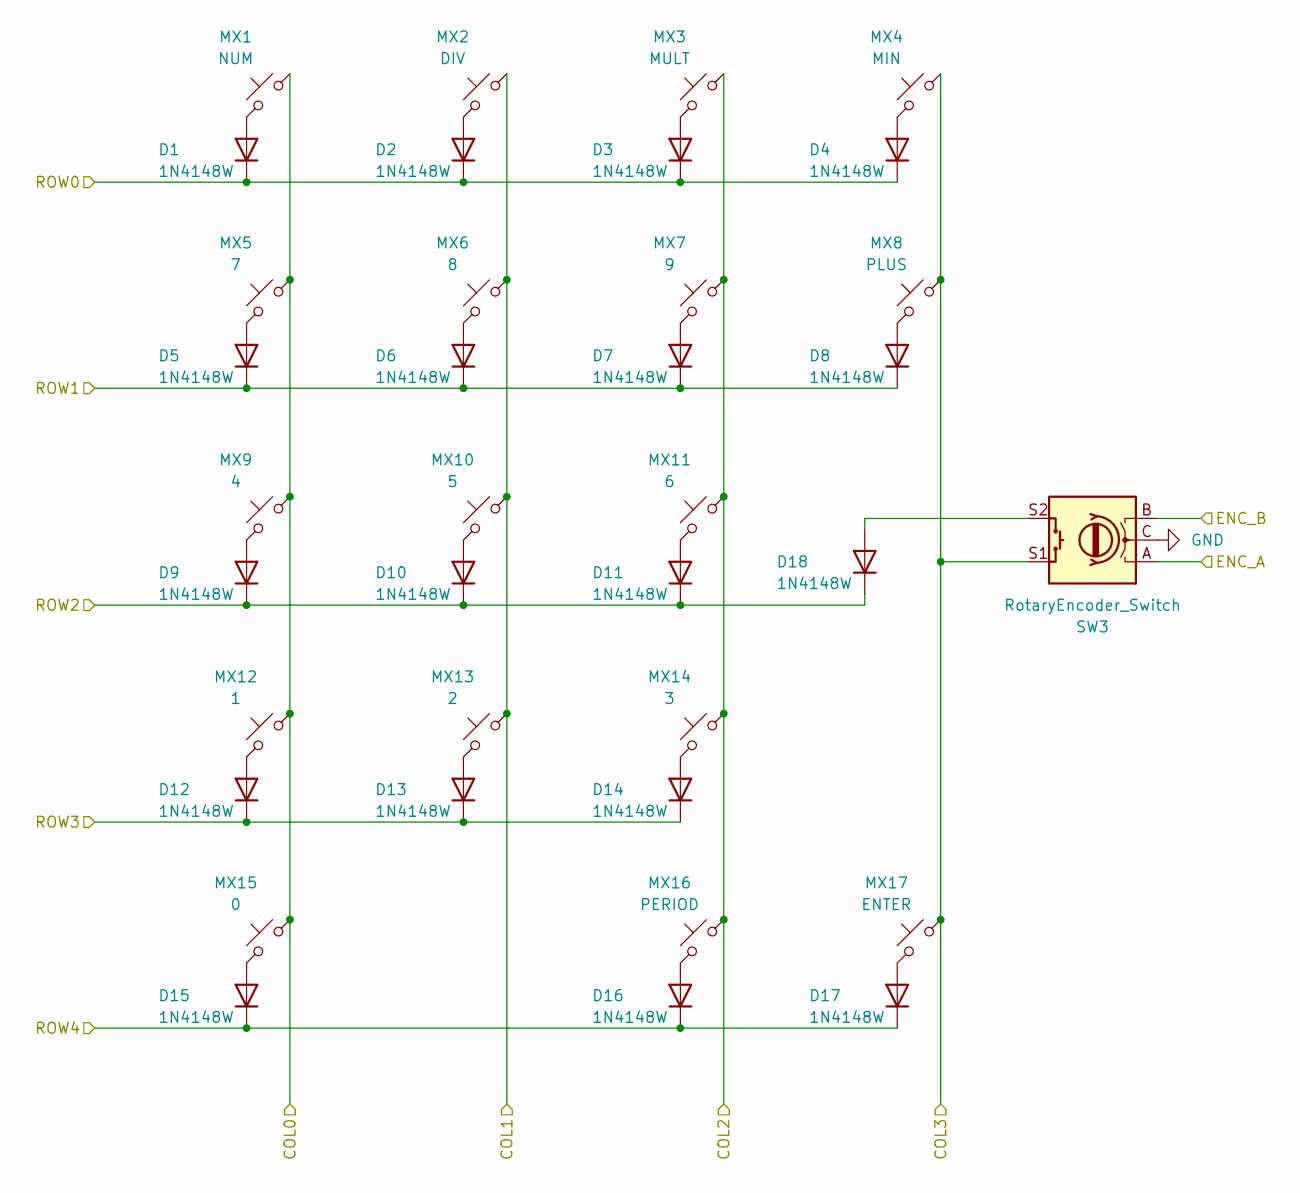
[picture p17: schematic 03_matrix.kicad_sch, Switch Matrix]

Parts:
D1, D2, D3, D4, D5, D6, D7, D8, D9, D10, D11, D12, D13, D14, D15, D16, D17, D18: 1N4148W; D_SOD-123
MX1: NUM; SW_MX_HS_CPG151101S11_1u
MX2: DIV; SW_MX_HS_CPG151101S11_1u
MX3: MULT; SW_MX_HS_CPG151101S11_1u
MX4: MIN; SW_MX_HS_CPG151101S11_1u
MX5: 7; SW_MX_HS_CPG151101S11_1u
MX6: 8; SW_MX_HS_CPG151101S11_1u
MX7: 9; SW_MX_HS_CPG151101S11_1u
MX8: PLUS; SW_MX_HS_CPG151101S11_1u
MX9: 4; SW_MX_HS_CPG151101S11_1u
MX10: 5; SW_MX_HS_CPG151101S11_1u
MX11: 6; SW_MX_HS_CPG151101S11_1u
MX12: 1; SW_MX_HS_CPG151101S11_1u
MX13: 2; SW_MX_HS_CPG151101S11_1u
MX14: 3; SW_MX_HS_CPG151101S11_1u
MX15: 0; SW_MX_HS_CPG151101S11_1u
MX16: PERIOD; SW_MX_HS_CPG151101S11_1u
MX17: ENTER; SW_MX_HS_CPG151101S11_1u
SW3: RotaryEncoder_Switch; RotaryEncoder_Alps_EC11E-Switch_Vertical_H20mm

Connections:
/02_mcu/COL0: MX1.2, MX5.2, MX9.2, MX12.2, MX15.2; also elsewhere on the board
/02_mcu/COL1: MX2.2, MX6.2, MX10.2, MX13.2; also elsewhere on the board
/02_mcu/COL2: MX3.2, MX7.2, MX11.2, MX14.2, MX16.2; also elsewhere on the board
/02_mcu/COL3: MX4.2, MX8.2, MX17.2, SW3.S1; also elsewhere on the board
/02_mcu/ENC_A: SW3.A; also elsewhere on the board
/02_mcu/ENC_B: SW3.B; also elsewhere on the board
/02_mcu/ROW0: D1.1 (K), D2.1 (K), D3.1 (K), D4.1 (K); also elsewhere on the board
/02_mcu/ROW1: D5.1 (K), D6.1 (K), D7.1 (K), D8.1 (K); also elsewhere on the board
/02_mcu/ROW2: D9.1 (K), D10.1 (K), D11.1 (K), D18.1 (K); also elsewhere on the board
/02_mcu/ROW3: D12.1 (K), D13.1 (K), D14.1 (K); also elsewhere on the board
/02_mcu/ROW4: D15.1 (K), D16.1 (K), D17.1 (K); also elsewhere on the board
GND: SW3.C; also elsewhere on the board
unnamed: D1.2 (A), MX1.1
unnamed: D2.2 (A), MX2.1
unnamed: D3.2 (A), MX3.1
unnamed: D4.2 (A), MX4.1
unnamed: D5.2 (A), MX5.1
unnamed: D6.2 (A), MX6.1
unnamed: D7.2 (A), MX7.1
unnamed: D8.2 (A), MX8.1
unnamed: D9.2 (A), MX9.1
unnamed: D10.2 (A), MX10.1
unnamed: D11.2 (A), MX11.1
unnamed: D12.2 (A), MX12.1
unnamed: D13.2 (A), MX13.1
unnamed: D14.2 (A), MX14.1
unnamed: D15.2 (A), MX15.1
unnamed: D16.2 (A), MX16.1
unnamed: D17.2 (A), MX17.1
unnamed: D18.2 (A), SW3.S2

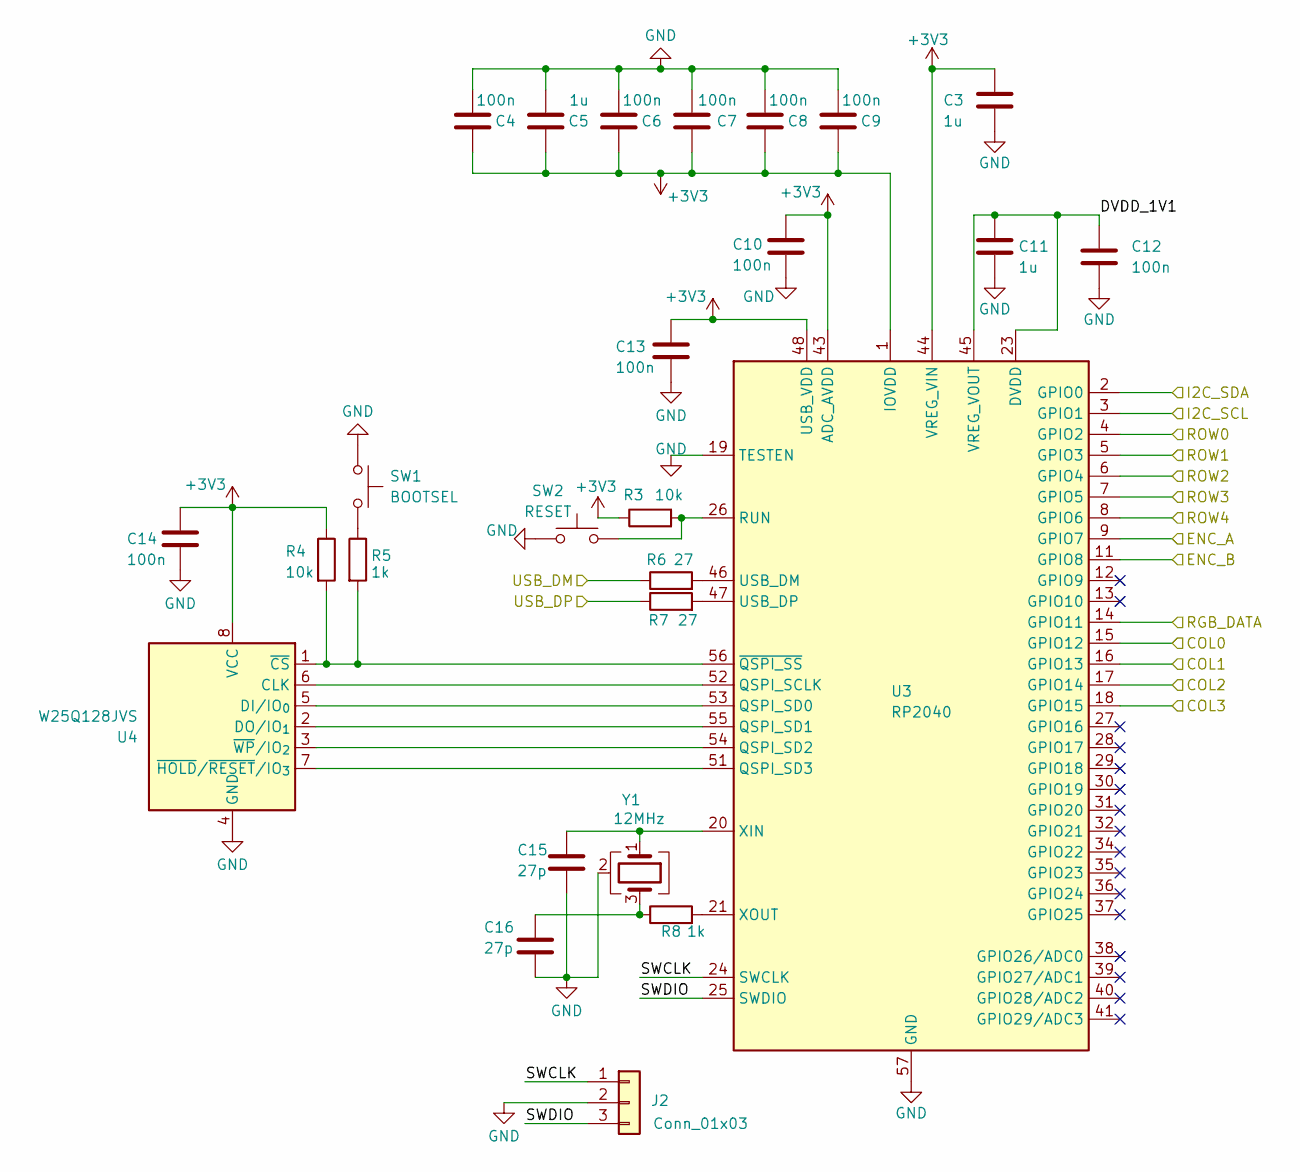
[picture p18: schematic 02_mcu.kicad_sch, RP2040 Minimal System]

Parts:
C3, C5, C11: 1u; C_0603_1608Metric
C4, C6, C7, C8, C9, C10, C12, C13, C14: 100n; C_0603_1608Metric
C15, C16: 27p; C_0603_1608Metric
J2: Conn_01x03; PinHeader_1x03_P2.54mm_Vertical
R3, R4: 10k; R_0603_1608Metric
R5, R8: 1k; R_0603_1608Metric
R6, R7: 27; R_0603_1608Metric
SW1: BOOTSEL; SW_SPST_PTS645Sx43SMTR92
SW2: RESET; SW_SPST_PTS645Sx43SMTR92
U3: RP2040; QFN-56-1EP_7x7mm_P0.4mm_EP3.2x3.2mm
U4: W25Q128JVS; SOIC-8_5.3x5.3mm_P1.27mm
Y1: 12MHz; Crystal_SMD_3225-4Pin_3.2x2.5mm

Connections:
+3V3: C3.1, C4.1, C5.1, C6.1, C7.1, C8.1, C9.1, C10.1, C13.1, C14.1, R3.1, R4.1, U3.1 (IOVDD), U3.10 (IOVDD), U3.22 (IOVDD), U3.33 (IOVDD), U3.42 (IOVDD), U3.43 (ADC_AVDD), U3.44 (VREG_VIN), U3.48 (USB_VDD), U3.49 (IOVDD), U4.8 (VCC); also elsewhere on the board
/01_power_usb/USB_DM: R6.1; also elsewhere on the board
/01_power_usb/USB_DP: R7.1; also elsewhere on the board
/02_mcu/COL0: U3.15 (GPIO12); also elsewhere on the board
/02_mcu/COL1: U3.16 (GPIO13); also elsewhere on the board
/02_mcu/COL2: U3.17 (GPIO14); also elsewhere on the board
/02_mcu/COL3: U3.18 (GPIO15); also elsewhere on the board
/02_mcu/DVDD_1V1: C11.1, C12.1, U3.23 (DVDD), U3.45 (VREG_VOUT), U3.50 (DVDD)
/02_mcu/ENC_A: U3.9 (GPIO7); also elsewhere on the board
/02_mcu/ENC_B: U3.11 (GPIO8); also elsewhere on the board
/02_mcu/I2C_SCL: U3.3 (GPIO1); also elsewhere on the board
/02_mcu/I2C_SDA: U3.2 (GPIO0); also elsewhere on the board
/02_mcu/RGB_DATA: U3.14 (GPIO11); also elsewhere on the board
/02_mcu/ROW0: U3.4 (GPIO2); also elsewhere on the board
/02_mcu/ROW1: U3.5 (GPIO3); also elsewhere on the board
/02_mcu/ROW2: U3.6 (GPIO4); also elsewhere on the board
/02_mcu/ROW3: U3.7 (GPIO5); also elsewhere on the board
/02_mcu/ROW4: U3.8 (GPIO6); also elsewhere on the board
/02_mcu/SWCLK: J2.1, U3.24 (SWCLK)
/02_mcu/SWDIO: J2.3, U3.25 (SWDIO)
GND: C3.2, C4.2, C5.2, C6.2, C7.2, C8.2, C9.2, C10.2, C11.2, C12.2, C13.2, C14.2, C15.2, C16.2, J2.2, SW1.1, SW2.1, U3.19 (TESTEN), U3.57 (GND), U4.4 (GND), Y1.2 (G), Y1.4 (G); also elsewhere on the board
unnamed: C16.1, R8.1, Y1.3
unnamed: R5.1, SW1.2
unnamed: U3.52 (QSPI_SCLK), U4.6 (CLK)
unnamed: U3.53 (QSPI_SD0), U4.5 (DI/IO_{0})
unnamed: U3.55 (QSPI_SD1), U4.2 (DO/IO_{1})
unnamed: U3.54 (QSPI_SD2), U4.3 (~WP/IO_{2})
unnamed: U3.51 (QSPI_SD3), U4.7 (~HOLD/~RESET/IO_{3})
unnamed: R3.2, SW2.2, U3.26 (RUN)
unnamed: R6.2, U3.46 (USB_DM)
unnamed: R7.2, U3.47 (USB_DP)
unnamed: C15.1, U3.20 (XIN), Y1.1
unnamed: R8.2, U3.21 (XOUT)
unnamed: R4.2, R5.2, U3.56 (~QSPI_SS), U4.1 (~CS)

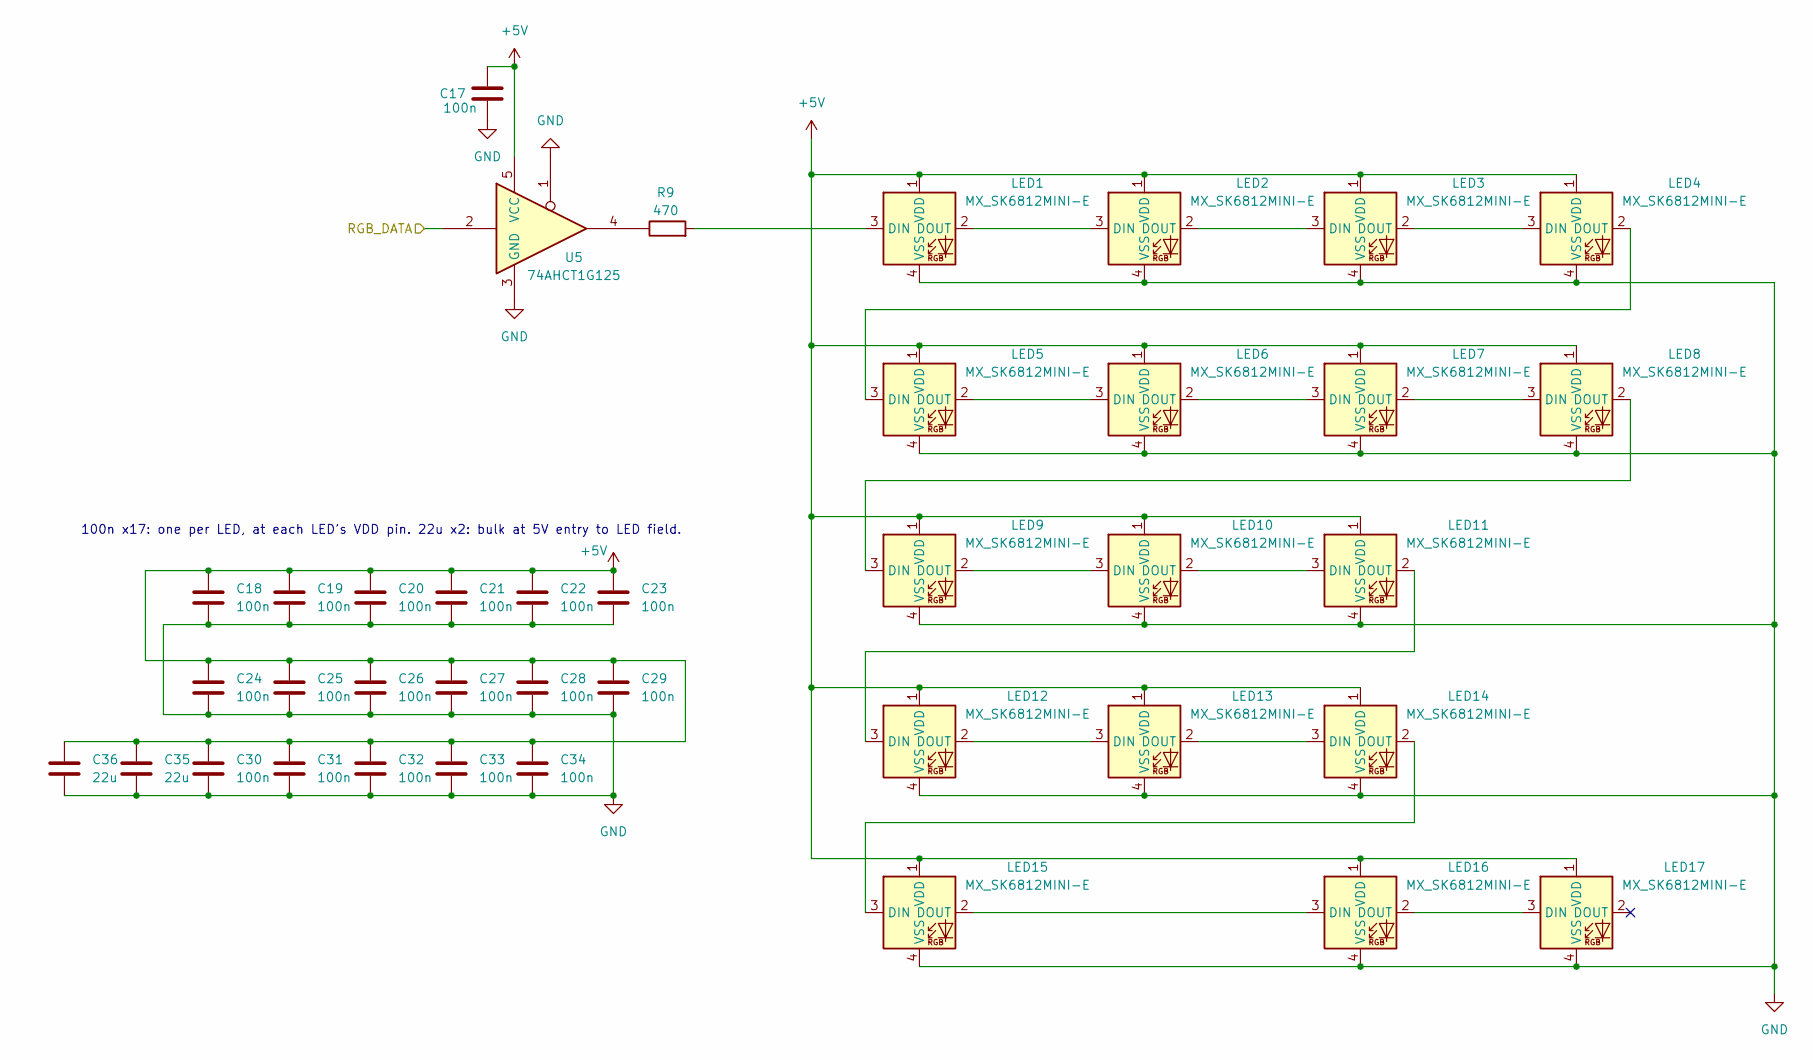
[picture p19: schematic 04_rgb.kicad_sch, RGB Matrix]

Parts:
C17, C18, C19, C20, C21, C22, C23, C24, C25, C26, C27, C28, C29, C30, C31, C32, C33, C34: 100n; C_0603_1608Metric
C35, C36: 22u; C_0805_2012Metric
LED1, LED2, LED3, LED4, LED5, LED6, LED7, LED8, LED9, LED10, LED11, LED12, LED13, LED14, LED15, LED16, LED17: MX_SK6812MINI-E; LED_MX_6028R
R9: 470; R_0603_1608Metric
U5: 74AHCT1G125; SOT-23-5

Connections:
+5V: C17.1, C18.1, C19.1, C20.1, C21.1, C22.1, C23.1, C24.1, C25.1, C26.1, C27.1, C28.1, C29.1, C30.1, C31.1, C32.1, C33.1, C34.1, C35.1, C36.1, LED1.1 (VDD), LED2.1 (VDD), LED3.1 (VDD), LED4.1 (VDD), LED5.1 (VDD), LED6.1 (VDD), LED7.1 (VDD), LED8.1 (VDD), LED9.1 (VDD), LED10.1 (VDD), LED11.1 (VDD), LED12.1 (VDD), LED13.1 (VDD), LED14.1 (VDD), LED15.1 (VDD), LED16.1 (VDD), LED17.1 (VDD), U5.5 (VCC); also elsewhere on the board
/02_mcu/RGB_DATA: U5.2; also elsewhere on the board
GND: C17.2, C18.2, C19.2, C20.2, C21.2, C22.2, C23.2, C24.2, C25.2, C26.2, C27.2, C28.2, C29.2, C30.2, C31.2, C32.2, C33.2, C34.2, C35.2, C36.2, LED1.4 (VSS), LED2.4 (VSS), LED3.4 (VSS), LED4.4 (VSS), LED5.4 (VSS), LED6.4 (VSS), LED7.4 (VSS), LED8.4 (VSS), LED9.4 (VSS), LED10.4 (VSS), LED11.4 (VSS), LED12.4 (VSS), LED13.4 (VSS), LED14.4 (VSS), LED15.4 (VSS), LED16.4 (VSS), LED17.4 (VSS), U5.1, U5.3 (GND); also elsewhere on the board
unnamed: LED1.3 (DIN), R9.2
unnamed: LED1.2 (DOUT), LED2.3 (DIN)
unnamed: LED2.2 (DOUT), LED3.3 (DIN)
unnamed: LED3.2 (DOUT), LED4.3 (DIN)
unnamed: LED4.2 (DOUT), LED5.3 (DIN)
unnamed: LED5.2 (DOUT), LED6.3 (DIN)
unnamed: LED6.2 (DOUT), LED7.3 (DIN)
unnamed: LED7.2 (DOUT), LED8.3 (DIN)
unnamed: LED8.2 (DOUT), LED9.3 (DIN)
unnamed: LED9.2 (DOUT), LED10.3 (DIN)
unnamed: LED10.2 (DOUT), LED11.3 (DIN)
unnamed: LED11.2 (DOUT), LED12.3 (DIN)
unnamed: LED12.2 (DOUT), LED13.3 (DIN)
unnamed: LED13.2 (DOUT), LED14.3 (DIN)
unnamed: LED14.2 (DOUT), LED15.3 (DIN)
unnamed: LED15.2 (DOUT), LED16.3 (DIN)
unnamed: LED16.2 (DOUT), LED17.3 (DIN)
unnamed: R9.1, U5.4

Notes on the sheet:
100n x17: one per LED, at each LED's VDD pin. 22u x2: bulk at 5V entry to LED field.

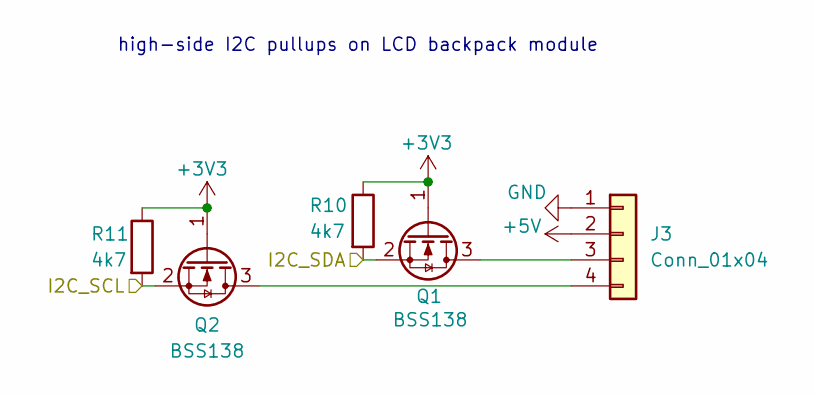
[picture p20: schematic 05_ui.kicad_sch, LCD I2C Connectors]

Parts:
J3: Conn_01x04; PinHeader_1x04_P2.54mm_Vertical
Q1, Q2: BSS138; SOT-23
R10, R11: 4k7; R_0603_1608Metric

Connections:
+3V3: Q1.1 (G), Q2.1 (G), R10.1, R11.1; also elsewhere on the board
+5V: J3.2; also elsewhere on the board
/02_mcu/I2C_SCL: Q2.2 (S), R11.2; also elsewhere on the board
/02_mcu/I2C_SDA: Q1.2 (S), R10.2; also elsewhere on the board
GND: J3.1; also elsewhere on the board
unnamed: J3.3, Q1.3 (D)
unnamed: J3.4, Q2.3 (D)

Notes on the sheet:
high-side I2C pullups on LCD backpack module

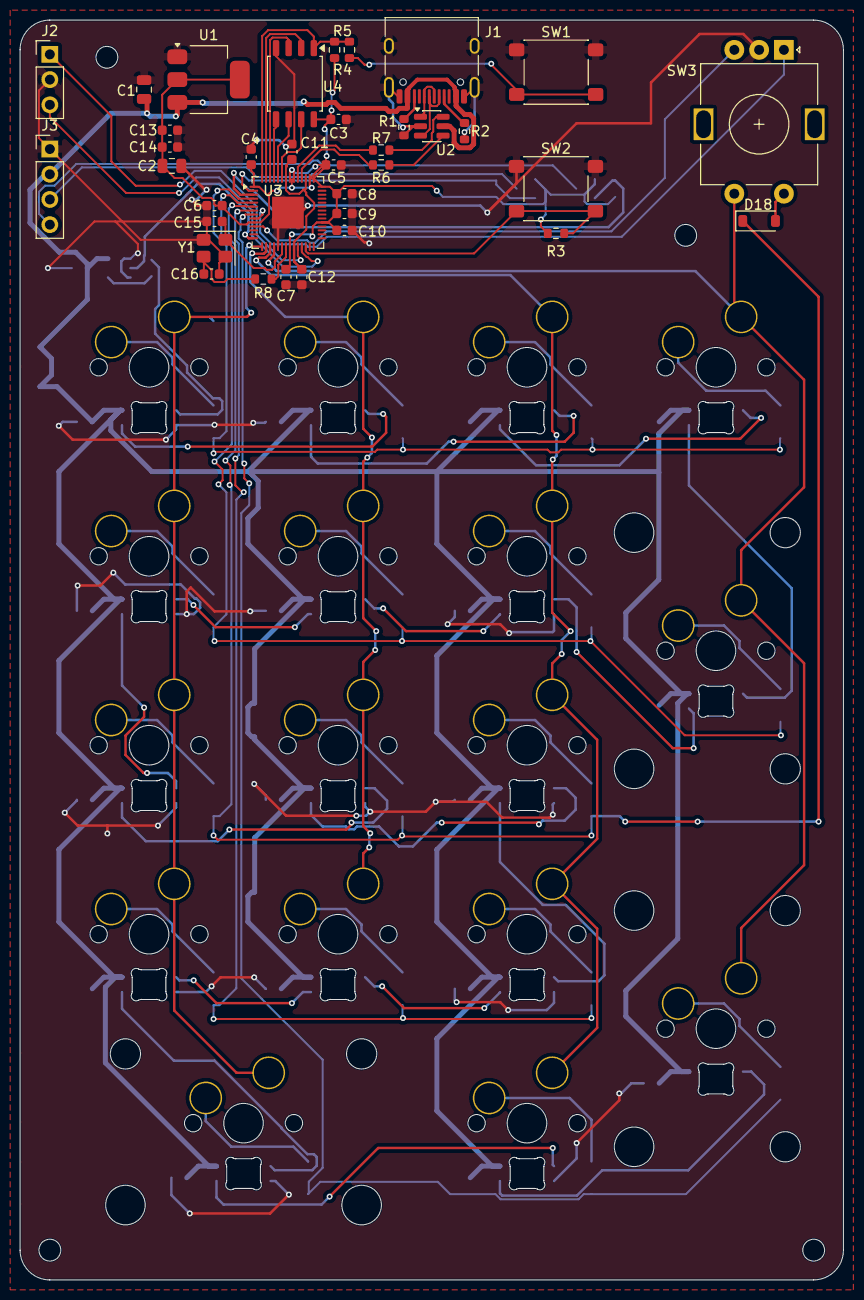
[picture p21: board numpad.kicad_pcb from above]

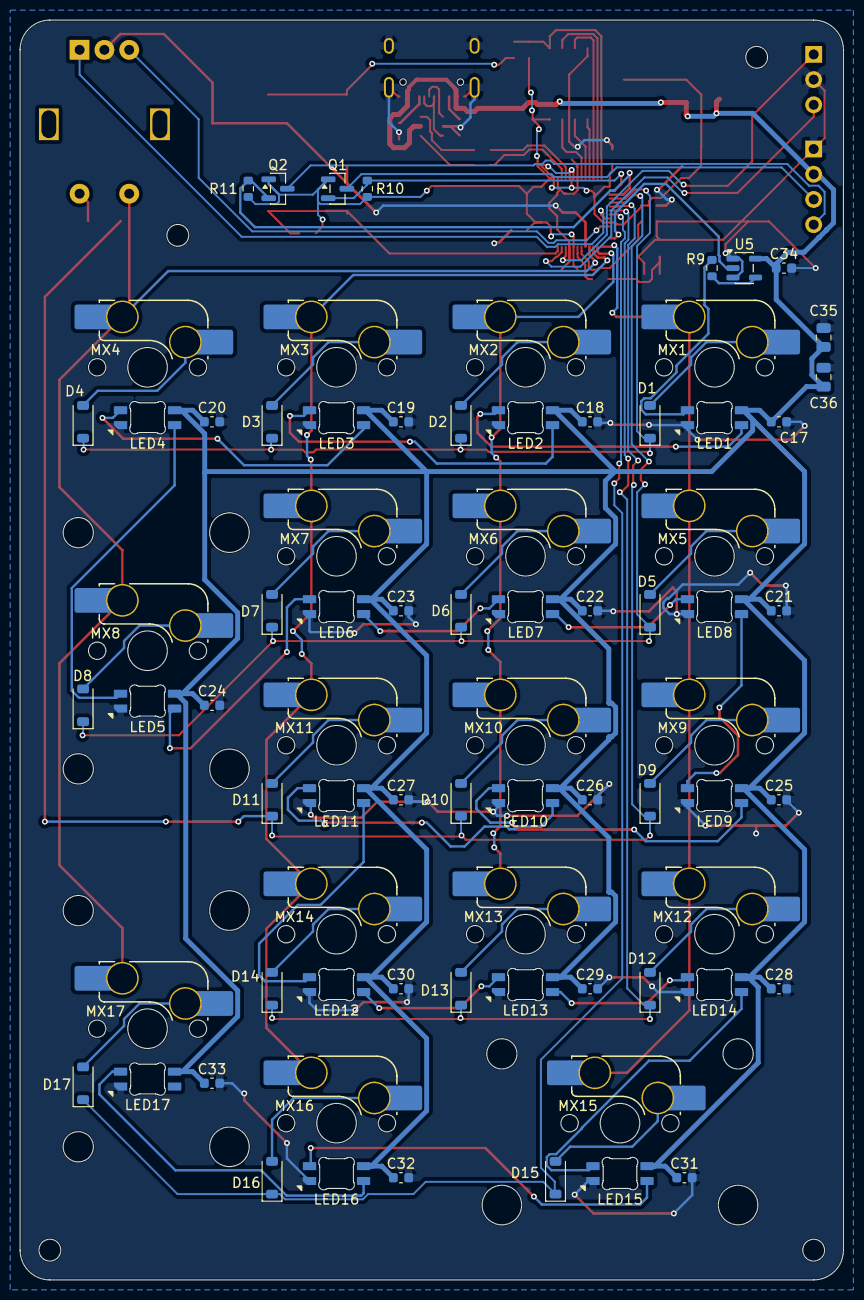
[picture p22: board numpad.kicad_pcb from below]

Board: 2 copper layers, 83.0 x 127.0 mm, 113 parts (77 on the bottom side), 77 nets.

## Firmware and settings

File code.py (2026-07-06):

# ------------------------------------------------------------------
# Production Version - 17-key USB numpad + LCD (Phase 7)
# Hardware: Raspberry Pi Pico W (RP2040), CircuitPython 9.2.1
#   Hand-wired 5x4 matrix, one diode per key
#   (anode toward row, cathode toward column)
#   Rows GP2-GP6, Cols GP12-GP15, LED GP11
#   16x2 LCD on PCF8574 I2C backpack @ 0x27, SCL GP1, SDA GP0
#
# Features:
#   • USB HID numeric keypad with event-driven matrix scanning
#     (keypad.KeyMatrix)
#   • LCD interface with switchable views:
#       - Clock + Environment Canada weather (4 locations)
#       - PC hardware statistics (4 pages)
#       - Calculator (operator precedence, local input capture)
#       - Lifetime keypress statistics
#   • NumLock functions as a momentary Fn modifier:
#       - View selection and cycling
#       - LED brightness adjustment (Fn+'+' / Fn+'-')
#   • Adjustable PWM keypad LED brightness with persistent storage
#   • Persistent settings stored in /count.txt:
#       - Lifetime keypress counter
#       - LED brightness
#   • Automatic LCD backlight and LED timeout after inactivity
#   • Optional host companion over USB CDC for:
#       - Time synchronization
#       - Weather
#       - PC hardware monitoring
#
# Design highlights:
#   • Edge-driven HID press/release handling
#   • Dirty-flag LCD rendering (no continuous redraws)
#   • Event-driven keypad scanning in firmware
#   • Host performs formatting and data collection; Pico acts as a
#     lightweight display/input device
# ------------------------------------------------------------------

import time
import board
import busio
import keypad
import usb_cdc
import usb_hid
import pwmio
from adafruit_hid.keyboard import Keyboard
from adafruit_hid.keycode import Keycode
from lcd import LCD
from i2c_pcf8574_interface import I2CPCF8574Interface

# ----------------------------
# CONSTANTS
# ----------------------------
# --- LCD geometry ---
LCD_COLS = 16                # number of character columns on the LCD
# --- timing / idle ---
IDLE_TIMEOUT_MS = 300_000    # inactivity time until screen and LEDs sleep
WX_STALE_MS = 30 * 60_000    # weather older than this shows as stale
STATS_STALE_MS = 15_000      # PC stats older than this show "no data"
# --- persistence ---
COUNT_FILE = "/count.txt"    # persistent store: keystroke count + LED brightness
FLUSH_EVERY = 100            # batch flash writes: save every N presses (idle also flushes)
# --- matrix key numbers (row * 4 + col) ---
FN_KEY = 0                   # NumLock, used as the Fn modifier
FN_BRIGHT_UP = 7             # '+' key: Fn combo raises LED brightness
FN_BRIGHT_DOWN = 3           # '-' key: Fn combo lowers LED brightness
# --- LCD views ---
VIEW_STATS = 1               # lifetime keypress counter
VIEW_CLOCK = 2               # clock + weather (default after splash)
VIEW_SPLASH = 3              # boot screen, transitions to clock
VIEW_PCSTATS = 4             # host PC stats, cycling pages
VIEW_CALC = 5                # calculator
STAT_PAGES = 4               # number of cycling PC-stat pages
WX_SLOTS = 4                 # number of preset weather locations
CALC_MAX_EXPR = 64           # hard cap on calc expression length
# --- key LEDs (white, PWM on GP11) ---
LED_STEP = 8192			     # brightness step per press (65535/8 = 8 levels + off)
LED_MIN = 0                  # minimum led strength
LED_MAX = 65535              # maximum led strength (16-bit PWM duty - 65,536 possible duty cycle values)

# ----------------------------
# TIME BASE
# ----------------------------
# current time in milliseconds
def now_ms():
    return time.monotonic_ns() // 1_000_000

SPLASH_DURATION_MS = 1500    # how long the boot splash stays before the clock
boot_time = now_ms()         # reference point for the splash timeout

# ----------------------------
# KEY MAP
# ----------------------------
# key_number = row * 4 + col ->
#   (HID keycode, Fn view or None, calculator symbol or None)
# Unwired matrix positions are intentionally omitted.
KEYS = {
    0:  (Keycode.KEYPAD_NUMLOCK, None, None),
    1:  (Keycode.KEYPAD_FORWARD_SLASH, None, "/"),
    2:  (Keycode.KEYPAD_ASTERISK, None, "*"),
    3:  (Keycode.KEYPAD_MINUS, None, "-"),
    4:  (Keycode.KEYPAD_SEVEN, None, "7"),
    5:  (Keycode.KEYPAD_EIGHT, None, "8"),
    6:  (Keycode.KEYPAD_NINE, None, "9"),
    7:  (Keycode.KEYPAD_PLUS, None, "+"),
    8:  (Keycode.KEYPAD_FOUR, None, "4"),
    9:  (Keycode.KEYPAD_FIVE, None, "5"),
    10: (Keycode.KEYPAD_SIX, None, "6"),
    12: (Keycode.KEYPAD_ONE, VIEW_PCSTATS, "1"),
    13: (Keycode.KEYPAD_TWO, VIEW_CALC, "2"),
    14: (Keycode.KEYPAD_THREE, VIEW_STATS, "3"),
    16: (Keycode.KEYPAD_ZERO, VIEW_CLOCK, "0"),
    18: (Keycode.KEYPAD_PERIOD, None, "."),
    19: (Keycode.KEYPAD_ENTER, None, "="),
}

# ----------------------------
# STORAGE
# ----------------------------
# load persistent lifetime press counter and led brightness state
def load_settings():
    try:
        with open(COUNT_FILE) as f:
            lines = f.read().splitlines()

        count = int(lines[0])

        if len(lines) > 1:
            brightness = int(lines[1])
            brightness = max(LED_MIN, min(LED_MAX, brightness))    # clamp to valid PWM range
        else:
            brightness = LED_MAX    # old file format

        return count, brightness

    except (OSError, ValueError, IndexError):
        return 0, LED_MAX    # missing/corrupt file: fresh defaults

def save_settings():
    global unsaved
    try:
        with open(COUNT_FILE, "w") as f:
            f.write("{}\n{}".format(
                press_count,
                led_brightness
            ))
        unsaved = 0    # reset the unsaved-press counter on a real write
    except OSError:
        pass    # ignore writes when storage is read-only (dev mode)

press_count, led_brightness = load_settings()
unsaved = 0    # presses accumulated since the last successful save

# ----------------------------
# HARDWARE INIT
# ----------------------------
# background matrix scanner (C-level, debounced, event queue).
matrix = keypad.KeyMatrix(
    row_pins=(board.GP2, board.GP3, board.GP4, board.GP5, board.GP6),
    column_pins=(board.GP12, board.GP13, board.GP14, board.GP15),
    columns_to_anodes=False,  # REQUIRED: diodes conduct row to column
    interval=0.010,
)

keyboard = Keyboard(usb_hid.devices)    # HID keyboard bound to the USB interface

# key-leds (white)
# GP11 drives all white key LEDs together, PWM gives brightness control.
# initial duty comes from the loaded setting so there's no flash-then-dim at boot.
led = pwmio.PWMOut(
    board.GP11,
    frequency=1000,
    duty_cycle=led_brightness
)

# push the current LED state to hardware: chosen brightness when awake,
# fully off when the display has slept. reads backlight_on/led_brightness
# as globals (both exist by the time this is first called in the loop).
def update_led():
    if backlight_on:
        led.duty_cycle = led_brightness
    else:
        led.duty_cycle = 0

i2c = busio.I2C(scl=board.GP1, sda=board.GP0)
lcd = LCD(I2CPCF8574Interface(i2c, 0x27), num_rows=2, num_cols=LCD_COLS)

serial = usb_cdc.data      # None if boot.py didn't enable it

# ----------------------------
# STATE
# ----------------------------
# Fn (Function) state
fn_down = False             # NumLock physically held
fn_used = False             # a digit was consumed during this hold
consumed = set()            # keys whose release event should be ignored

view = VIEW_SPLASH          # default view
view_dirty = True           # set on any visible change, cleared after a render

backlight_on = True         # shadow of the (write-only) backlight/LED on-state
last_activity = now_ms()    # timestamp of the last key event, for idle timeout

# ----------------------------
# TIME SYNC STATE
# ----------------------------
synced = False          # False until the first host time message, clock shows UNKNOWN
epoch_at_sync = 0       # unix epoch (home-local) from last host message
ms_at_sync = 0          # monotonic ms when that message arrived
clock_shown = ""        # last strings rendered on the clock view

# reconstruct current time by free-running from the last sync anchor
# (host re-syncs periodically, so drift never exceeds one broadcast interval)
def current_epoch(t):
    return epoch_at_sync + (t - ms_at_sync) // 1000    # free-run: anchor epoch + elapsed monotonic time since anchor

rx_buf = b"" # partial-line accumulator for serial input

# ----------------------------
# PC STATS STATE
# ----------------------------
stat_lines = [["", ""] for _ in range(STAT_PAGES)]    # host-formatted display lines, [page][row]; '*' -> degree at draw
stats_rx_ms = 0          # receipt time of last stat message (0 = never); for staleness
stat_page = 0            # page shown on the PC stats view

# ----------------------------
# WEATHER STATE
# ----------------------------
wx = [None] * WX_SLOTS   # each: (label, cond, temp, offset_min), None until first msg
wx_rx_ms = 0             # receipt time of last weather message; for staleness
wx_index = 0             # location shown on the clock view

# ----------------------------
# CALCULATOR STATE
# ----------------------------
# expr   - expression string as typed ("2+3*4")
# result - result string after Enter, or None
# error  - True after div-by-zero/malformed; next digit clears
calc_expr = ""
calc_result = None
calc_error = False

OPS = "+-*/"    # the four supported operator characters

# reset the calculator to empty (also used as clear-entry)
def calc_clear():
    global calc_expr, calc_result, calc_error
    calc_expr = ""
    calc_result = None
    calc_error = False

# format a numeric result for the row: whole numbers drop the ".0",
# anything too wide for the 16-char row (minus the '=') falls back to sci notation
def calc_display(v):
    # exact int when possible; scientific if too wide for the row
    if v == int(v):
        v = int(v)
    s = str(v)
    if len(s) <= LCD_COLS - 1:      # -1 for the '=' prefix
        return s
    return "{:.6e}".format(v)

# evaluate a full expression with PEMDAS via two reduction passes.
# input rules guarantee tokens strictly alternate number/op, so no parser
# stack is needed. returns a display string, or None on any error
def calc_eval(expr):
    """PEMDAS for + - * / by two-pass reduction.
    Returns result string, or None on error."""
    if expr and expr[-1] in OPS:
        expr = expr[:-1]            # trailing operator: ignore
    if not expr:
        return None

    # tokenize: numbers and operators, strictly alternating
    tokens = []
    num = ""
    for ch in expr:
        if ch in OPS:
            tokens.append(num)
            tokens.append(ch)
            num = ""
        else:
            num += ch
    tokens.append(num)

    # even indices are numbers, odd indices are operators
    try:
        vals = [float(tokens[i]) for i in range(0, len(tokens), 2)]
    except ValueError:
        return None                 # malformed number, e.g. "."
    ops = [tokens[i] for i in range(1, len(tokens), 2)]

    # pass 1: fold * and / left-to-right (higher precedence)
    # i does not advance after a fold: the next op slides into index i.
    i = 0
    while i < len(ops):
        if ops[i] in "*/":
            if ops[i] == "/" and vals[i + 1] == 0:
                return None    # divide by zero -> error
            vals[i] = (vals[i] * vals[i + 1] if ops[i] == "*"
                       else vals[i] / vals[i + 1])
            del vals[i + 1]
            del ops[i]
        else:
            i += 1

    # pass 2: sum the remaining +/- terms
    acc = vals[0]
    for op, v in zip(ops, vals[1:]):
        acc = acc + v if op == "+" else acc - v
    return calc_display(acc)

# handle one captured calculator keypress (digit, '.', operator, or '=')
def calc_key(sym):
    global calc_expr, calc_result, calc_error
    if sym in "0123456789.":
        if calc_error or calc_result is not None:
            calc_clear()            # digit after result/error: fresh start
        if sym == ".":
            # one '.' per number: scan back to the last operator
            tail = calc_expr
            for op in OPS:
                tail = tail.split(op)[-1]
            if "." in tail:
                return    # this number already has a decimal point
        if len(calc_expr) < CALC_MAX_EXPR:
            calc_expr += sym
        return

    if sym in OPS:
        if calc_error:
            return    # operators do nothing while in error state
        if calc_result is not None:
            # operator after result: continue from the result
            calc_expr = calc_result
            calc_result = None
        if not calc_expr:
            return                  # no leading operator (no unary minus)
        if calc_expr[-1] in OPS:
            calc_expr = calc_expr[:-1] + sym   # replace repeated op
        else:
            calc_expr += sym
        return

    # sym == "=": evaluate
    if calc_error or not calc_expr or calc_result is not None:
        return    # nothing to do
    r = calc_eval(calc_expr)
    if r is None:
        calc_error = True
    else:
        calc_result = r

# the two calculator rows: expression (scrolled to its tail) and result/error
def calc_rows():
    top = calc_expr[-LCD_COLS:]     # scroll: show the tail
    if calc_error:
        return (top, "Error")
    if calc_result is not None:
        return (top, "=" + calc_result)
    return (top, "")

# ----------------------------
# SERIAL
# ----------------------------
# dispatch one parsed host message. unknown keys are ignored, which is how
# the protocol stays forward-compatible: new host messages can't break old firmware.
def handle_message(key, value):
    global synced, epoch_at_sync, ms_at_sync
    global view_dirty, stats_rx_ms, wx_rx_ms
    if key == "time":
        try:
            epoch_at_sync = int(value)
        except ValueError:
            return
        ms_at_sync = now_ms()
        synced = True
    elif len(key) == 3 and key[0] == "p" and key[2] in "ab":
        # p{page}{row}: pre-formatted stat line from the host
        try:
            page = int(key[1])
        except ValueError:
            return
        if 0 <= page < STAT_PAGES:
            stat_lines[page][0 if key[2] == "a" else 1] = value
            stats_rx_ms = now_ms()
            if view == VIEW_PCSTATS and page == stat_page:
                view_dirty = True
    elif key.startswith("wx"):
        # wx{slot}: label,cond,temp,offset_min for one weather location
        try:
            slot = int(key[2:])
            label, cond, temp, off = value.split(",")
            entry = (label, cond, int(temp), int(off))
        except (ValueError, IndexError):
            return
        if 0 <= slot < WX_SLOTS:
            wx[slot] = entry
            wx_rx_ms = now_ms()
            if view == VIEW_CLOCK:
                view_dirty = True

def poll_serial():
    # non-blocking: consume whatever bytes are waiting, act on
    # complete lines, keep the remainder buffered. A line may
    # arrive split across polls; rx_buf carries the partial.
    global rx_buf
    if serial is None or serial.in_waiting == 0:
        return
    rx_buf += serial.read(serial.in_waiting)
    while b"\n" in rx_buf:
        line, rx_buf = rx_buf.split(b"\n", 1)
        try:
            text = line.decode().strip()
        except UnicodeError:
            continue    # skip non-UTF-8 lines
        if ":" in text:
            key, value = text.split(":", 1)    # split on first ':' only
            handle_message(key, value)

# ----------------------------
# DISPLAY
# ----------------------------

DEGREE = chr(0xDF)      # degree symbol in the HD44780 character ROM

# one PC-stats row for the current page, or a staleness placeholder
def stat_row(row, t):
    if (t - stats_rx_ms) > STATS_STALE_MS or stats_rx_ms == 0:
        return "no data" if row == 0 else ""
    # '*' is the host's placeholder for the degree symbol
    return stat_lines[stat_page][row].replace("*", DEGREE)

# clock-view row 0: current location's weather, or a placeholder if absent/stale
def weather_line(t):
    entry = wx[wx_index]
    if entry is None:
        return "no weather"
    label, cond, temp, _ = entry
    if (t - wx_rx_ms) > WX_STALE_MS:
        return label + " --"    # stale: label with no data
    return "{} {} {}{}".format(label, cond, temp, DEGREE)

# clock-view row 1: date/time in the displayed location's local time
# (host-supplied offset_min shifts the home-local epoch)
def clock_string(t):
    if not synced:
        return "UNKNOWN"
    entry = wx[wx_index]
    off_min = entry[3] if entry is not None else 0
    tm = time.localtime(current_epoch(t) + off_min * 60)
    return "{:04}/{:02}/{:02} {:02}:{:02}".format(
        tm.tm_year, tm.tm_mon, tm.tm_mday, tm.tm_hour, tm.tm_min)

def clock_rows(t):
    # both clock-view rows as one tuple, so the refresh check and
    # the renderer compare/draw the same thing
    return (weather_line(t), clock_string(t))

def pcstats_rows(t):
    # both PC-stats rows as one tuple, matching the clock's refresh pattern
    return (stat_row(0, t), stat_row(1, t))

# write one full LCD row, padded/truncated to width, so old content is
# overwritten without a clear() (clear() is slow and blanks both rows)
def draw_line(row, text):
    lcd.set_cursor_pos(row, 0)
    lcd.print((text + " " * LCD_COLS)[:LCD_COLS])

# draw the active view's two rows; caches the "shown" tuples for the
# time-varying views so the loop's refresh check can detect real changes
def render(t):
    global clock_shown, pcstats_shown
    if view == VIEW_SPLASH:
        draw_line(0, "pico-numpad")
        draw_line(1, "")
    elif view == VIEW_CLOCK:
        clock_shown = clock_rows(t)
        draw_line(0, clock_shown[0])
        draw_line(1, clock_shown[1])
    elif view == VIEW_STATS:
        draw_line(0, "Presses:")
        draw_line(1, str(press_count))
    elif view == VIEW_PCSTATS:
        pcstats_shown = pcstats_rows(t)
        draw_line(0, pcstats_shown[0])
        draw_line(1, pcstats_shown[1])
    elif view == VIEW_CALC:
        rows = calc_rows()
        draw_line(0, rows[0])
        draw_line(1, rows[1])

pcstats_shown = ("", "")    # last-rendered PC-stats rows (compared each loop)

# ----------------------------
# INIT DISPLAY
# ----------------------------
# initial LCD state
lcd.clear()
lcd.set_backlight(True)
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

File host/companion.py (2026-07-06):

# ------------------------------------------------------------------
# companion.py - host-side broadcaster for pico-numpad
#
# Sends over the Pico's data serial port (auto-detected):
#   time:<epoch>                     on connect + every 30 s
#   p{0-3}{a,b}:<16-char line>       every STATS_INTERVAL_S
#     pre-formatted PC stat page rows; '*' renders as a degree
#     symbol on the Pico. Pages: 0 overview, 1 memory, 2 clocks,
#     3 voltages. Missing sensors render as '--'.
#   wx<i>:<LABEL>,<COND>,<TEMP>,<OFFMIN>  every WX_INTERVAL_S
#
# Sources:
#   stats  - LibreHardwareMonitor web server (localhost:8085),
#            running as admin. Down -> stat lines say 'LHM down'.
#   weather- Environment Canada via env_canada. Down -> wx skipped.
#
# Sensor matching: hardware prefix + path kind + display name
# (numeric indices shift between LHM versions). Names target this
# PC (i7-13700K, RTX 4080, 2x Corsair DDR5); adjust for others.
#
# Deps: pip install pyserial requests env_canada
# Logging: rotating file beside this script (LOG_FILE constant,
#   500 KB x 2 backups). No console output; under pythonw.exe
#   there is no console, so print() would be silently lost.
# Auto-start: Task Scheduler at logon, pythonw.exe as the program
#   and this script as the argument. Full setup, watchdog trigger,
#   and Store-stub warning: see host/README.md
# ------------------------------------------------------------------

import asyncio
import time
from datetime import datetime
from zoneinfo import ZoneInfo

import serial
import serial.tools.list_ports
import requests
from env_canada import ECWeather
import logging
from logging.handlers import RotatingFileHandler
import os

LOG_FILE = os.path.join(os.path.dirname(os.path.abspath(__file__)), "companion.log")

logging.basicConfig(
    handlers=[RotatingFileHandler(
        LOG_FILE,
        maxBytes=500_000, backupCount=2)],
    level=logging.INFO,
    format="%(asctime)s %(levelname)s %(message)s",
)


PORT = None
TIME_INTERVAL_S = 30
STATS_INTERVAL_S = 2
WX_INTERVAL_S = 600
LHM_URL = "http://localhost:8085/data.json"
ADAFRUIT_VID = 0x239A
HOME_TZ = ZoneInfo("America/Toronto")

LOCATIONS = [
    ("OTT",  (45.42, -75.70),  "America/Toronto"),
    ("MTL",  (45.51, -73.57),  "America/Toronto"),
    ("VAN",  (49.28, -123.12), "America/Vancouver"),
    ("PEMB", (45.83, -77.11),  "America/Toronto"),
]

COND_MAP = {
    "sunny": "Sunny", "clear": "Clear",
    "mainly sunny": "Sunny", "mainly clear": "Clear",
    "partly cloudy": "PtCldy", "mostly cloudy": "Cloudy",
    "cloudy": "Cloudy", "overcast": "Cloudy",
    "rain": "Rain", "heavy rain": "Rain",
    "light rain": "Rain", "light rainshower": "Shower",
    "rainshower": "Shower", "showers": "Shower", "drizzle": "Drizzl",
    "snow": "Snow", "light snow": "Snow", "flurries": "Flurry",
    "light snowshower": "Flurry", "thunderstorm": "Storm",
    "thunderstorms": "Storm", "fog": "Fog", "mist": "Mist",
    "haze": "Haze",
}

wx_stations = [ECWeather(coordinates=coord) for _, coord, _ in LOCATIONS]


def find_port():
    if PORT:
        return PORT
    candidates = sorted(
        p.device for p in serial.tools.list_ports.comports()
        if p.vid == ADAFRUIT_VID
    )
    return candidates[1] if len(candidates) >= 2 else None


def local_epoch():
    return int(time.time() - time.timezone + time.daylight * 3600)


def cond_short(raw):
    if not raw:
        return "--"
    return COND_MAP.get(raw.strip().lower(), raw.strip()[:6])


def tz_offset_min(tzname):
    now = datetime.now()
    loc = ZoneInfo(tzname).utcoffset(now.astimezone(ZoneInfo(tzname)))
    home = HOME_TZ.utcoffset(now.astimezone(HOME_TZ))
    return int((loc - home).total_seconds() // 60)


def read_weather():
    out = []
    for i, ((label, _, tzname), st) in enumerate(zip(LOCATIONS, wx_stations)):
        try:
            asyncio.run(st.update())
            temp = st.conditions.get("temperature", {}).get("value")
            cond = st.conditions.get("condition", {}).get("value")
            if temp is None:
                continue
            out.append((i, label, cond_short(cond), round(temp),
                        tz_offset_min(tzname)))
        except Exception as e:
            logging.warning("wx %s failed: %s", label, e)
    return out


# ---------------- LHM stats -> formatted page lines ----------------

def walk(node, out):
    for child in node.get("Children", []):
        walk(child, out)
    if "SensorId" in node:
        out[node["SensorId"]] = (node.get("Text", ""), node.get("Value", ""))


def parse_float(text):
    try:
        return float(text.split()[0].replace(",", "."))
    except (ValueError, IndexError, AttributeError):
        return None
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

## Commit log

2026-07-02 Initial LCD Implementation: non-blocking LCD display manager. Fix LCD geometry to 16x2
    [code.py]
2026-07-02 Add splash and clock views; rework Fn map; clean up comments and dead code
    [code.py]
2026-07-03 Add persistent LED brightness control with Fn shortcuts
    [code.py]
2026-07-03 Adjust LED max brightness
2026-07-03 Add persistent LED brightness control and update documentation (replace Phase format with overview format in code.py header
    [code.py]
2026-07-03 Add image of macropad wiring
2026-07-06 Add file logging for windowless operation
    Under pythonw there is no console, so print() is a no-op and
    crashes leave no trace. Replace prints with logging to a rotating
    file (500 KB x 2 backups), written beside the script via a
    LOG_FILE constant. Wrap the main loop in main() so uncaught
    exceptions log a traceback and exit non-zero, triggering Task
    Scheduler's failure restart. Update the header: logging notes,
    and point auto-start details at host/README.md.
    [companion.py]
2026-07-06 Clarify LED brightness and status in README
    Updated README to clarify adjustable keypad LED brightness and key LED status.
2026-07-15 add KiCad project scaffold for numpad PCB
    [numpad.kicad_pcb, numpad.kicad_sch]
2026-07-15 register marbastlib symbol and footprint libraries (project-local)
2026-07-16 fp-lib-table change plus schematic
    [01_power_usb.kicad_sch, 02_mcu.kicad_sch, 03_matrix.kicad_sch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]
2026-07-16 MCU schematic sheet: RP2040 minimal system
    [02_mcu.kicad_sch]
2026-07-16 matrix sheet, encoder, root hierarchy wired
    [01_power_usb.kicad_sch, 02_mcu.kicad_sch, 03_matrix.kicad_sch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]
2026-07-16 RGB chain with level shifter
    [04_rgb.kicad_sch, numpad.kicad_sch]
2026-07-16 LCD header with I2C level shifting, schematic complete
    [05_ui.kicad_sch, numpad.kicad_sch]
2026-07-17 Format cleanup, titles
    [01_power_usb.kicad_sch, 02_mcu.kicad_sch, 03_matrix.kicad_sch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]
2026-07-17 footprints set
    [01_power_usb.kicad_sch, 02_mcu.kicad_sch, 03_matrix.kicad_sch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]
2026-07-17 board setup: JLC rules, power net class
    [numpad.kicad_pcb]
2026-07-17 key field placed, outline and mounting holes
    [numpad.kicad_pcb]
2026-07-18 add key field diodes and LED caps
    [numpad.kicad_pcb]
2026-07-18 USB entry and MCU cluster
    [numpad.kicad_pcb]
2026-07-18 MCU cluster complete
    [numpad.kicad_pcb]
2026-07-18 RGB spine, placement complete
    [numpad.kicad_pcb]
2026-07-18 placement, ground pour complete, DRC clean
    [numpad.kicad_pcb]
2026-07-19 pours and final placement
    [numpad.kicad_pcb]
2026-07-20 component repositioning, more routing
    [numpad.kicad_pcb]
2026-07-20 led/sw matrix routing done
    [numpad.kicad_pcb]
2026-07-23 full layout-first 0 error DRC
    [numpad.kicad_pcb]
2026-07-24 throughholes added/bottom board extended, c3/c5/c11 schem value fixed
    [02_mcu.kicad_sch, numpad.kicad_pcb]
2026-07-24 pcbway export
    [numpad-Edge_Cuts.dxf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]
2026-07-24 remove hole ref text
    [numpad-B_Cu.gbr, numpad-B_Mask.gbr, numpad-B_Paste.gbr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]
2026-07-24 Add README for pico-numpad hardware design
    Added detailed README for pico-numpad hardware design, including features, repository layout, board summary, key matrix, notable ICs, ordering instructions, assembly guidelines, and firmware notes.
2026-08-01 stencil files
    [numpad-B_Paste.gbp, numpad-Edge_Cuts.gm1, numpad-F_Paste.gtp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]
2026-09-10 Revise README with status updates and details
    Updated the README to reflect the current status of the hardware project, including assembly progress and firmware development.
2026-09-10 Revise README for PCB and feature updates
    Updated README to reflect the transition from a hand-wired prototype to a custom rev A PCB with integrated USB-C and RGB per-key lighting.
